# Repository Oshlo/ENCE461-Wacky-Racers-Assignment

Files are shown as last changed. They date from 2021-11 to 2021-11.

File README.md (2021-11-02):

Wacky Racers
===============

This contains a directory structure for your assignment.

doc -- documentation

hw  -- hardware

src -- source code

Assignment Instructions
-----------

The [instructions](https://eng-git.canterbury.ac.nz/wacky-racers/wacky-racers/-/raw/master/doc/instructions/instructions.pdf)
are in a PDF file stored in this repository (you'll also get a copy when you
fork the project)

Downloading
-----------

Your group leader should create a forked copy of the wacky-racers
git project and then add the other group members to the project.  This
can be done by:

1. Go to https://eng-git.canterbury.ac.nz/wacky-racers/wacky-racers

2. Click 'Fork' button.  This will create your own copy of the repository.

3. Click on the ‘Settings’ menu then click the 'Expand' button for
'Sharing and permissions'.  Change 'Project Visibility' to 'Private'.

4. Click on the 'Members' menu and add group members as Developers.

5. Using bash terminal (or other useful shell), enter the command:

```
$ git clone git@eng-git.canterbury.ac.nz:your-userid/wacky-racers.git
```

Note: this *requires* that you have setup SSH keys on your machine and added
them to your account. See
https://docs.gitlab.com/ee/ssh/#generating-a-new-ssh-key-pair for instructions
on generating an SSH key pair.

Or if you don't want to set up your SSH keys, you can clone using the HTTPS
protocol (we recommend the above method as it allows automatic authentication
without entering your password every single time you want to make changes):

```
$ git clone https://eng-git.canterbury.ac.nz/your-userid/wacky-racers.git
```

6. Add the original wacky-racers repository as upstream. This will allow you to
   pull updates/bug fixes we make during the assignment.
```
$ cd wacky-racers
$ git remote add upstream https://eng-git.canterbury.ac.nz/wacky-racers/wacky-racers.git
```

7. If we add more demo code or tweak the instructions, you can pull the updated
   stuff using
```
$ git pull upstream master
```

Visual Studio Code
------------------

VS Code is a modern and highly versatile text editor. With the right extensions,
it can be used to develop code for just about anything! This project has been
configured for VS Code on the ESL computers (but its relatively easy to modify
it to work on a home computer, be it Windows, Linux, or Mac). For the simplest
use, simply go `File -> Open Folder` and point it at the `wacky-racers`
repository. This will give you access to the build tools (CTRL-SHIFT-B) that
have been setup. These must be run from inside a program (i.e. ledflash1.c).
Finally, opening a program and pressing F5 will launch a debugging session that
will allow the use of breakpoints and variable inspection.

When building your programs, the BOARD configuration variable must be set. In VS
Code this is done by choosing your C++ configuration (bottom right of the
window) which by default will be either `hat` or `racer`.

As a side note, the compilation and debugging requires the installation of two
VS Code extensions:
* C/C++ (Microsoft)
* Native Debug (Web Freak)
  VS Code should automatically prompt you to install these when you open the
  wacky-racers directory.

Configuration
-------------

The src/boards directory contains a number of configurations; one for
the hat and racer boards.  Each configuration directory contains three
files:

* board.mk  --- this is a makefile fragment that specifies the MCU model, optimisation level, etc.
* target.h  --- this is a C header file that defines the PIO pins and clock speeds.
* config.h  --- this is a C header file that wraps target.h.  It's purpose is for porting to different compilers.

You will need to edit the target.h file for your board.

Compilation
-----------

Compilation requires a bare-metal ARM GCC toolchain arm-none-eabi.
See
http://ecewiki.elec.canterbury.ac.nz/mediawiki/index.php/ARM_toolchain
for installation details.

Compilation is performed using makefiles, since each application
requires many files.  Rather than having large makefiles, a heirarchy
of makefile fragments is employed.  Dependencies are automatically generated.

A board description can be selected with the BOARD environment
variable.  This can be defined for each command, for example,

```
$ BOARD=racer make program
```

Alternatively, this can be defined for a session

```
$ export BOARD=racer
$ make program
```

Before you can flash any code to the MCU, you need to disable the write-protection
bit in the non-volatile memory. This will need to be done once, and only needed again
if you erase your flash memory.
```
$ make bootflash
```

Each of the makefiles has the following phony targets:
* all  --- compile the application
* program --- compile the application and download to the MCU (you need Openocd running as a daemon)
* debug --- start the debugger GDB (you need Openocd running as a daemon)
* reset --- reset your MCU (you need Openocd running as a daemon)
* clean --- delete the executable and object files.   This is necessary when compiling for a different board.
* bootflash -- this needs to done once to set a bit in the SAM4S so that it will run your application and not its bootloader on reset.

Demo applications
-----------------

These are found in the test-apps directory.  These are board
independent and thus the specific board must be selected with the
BOARD environment variable.  Note, when debugging hardware it is much easier
to use a small test program rather than a large application.

There a number of variations of each test program.  As a rule, the larger the number, the fancier the level of abstraction.

I suggest trying the following programs:
* ledflash1 You will need to correctly define LED1_PIO in boards/xxxx/target.h  If this program does not run see  http://ecewiki.elec.canterbury.ac.nz/mediawiki/index.php/SAM4S_getting_started.
* pwm_test1 You will need to edit pwm_test1.c and define PWM1_PIO for an available PWM pin.  This program is useful for checking that the phase-locked loop (PLL) is correctly configured to generate the correct CPU clock frequency.  You should see a 100 kHz square wave using an oscilloscope connected to the specified PIO pin (provided it can be driven from the PWM peripheral).
* usb_vbus_test1 This will turn a LED on if the USB VBUS signal is detected when a USB cable is connected to a computer.  It is a simple example of using a PIO as an input.
* usbserial_hello1 This will repeatedly send "Hello world" to a computer via the USB CDC protocol.  If you have connected a USB cable to a computer running Linux, the Linux dmesg command should say someting about ttyACM0 detected.  If not see the troubleshooting section.   For more details, see http://ecewiki.elec.canterbury.ac.nz/mediawiki/index.php/USB_CDC.
* adc_test1 This reads from the AD5 and AD6 analogue inputs and prints the values to a computer with the USB CDC protocol.

Troubleshooting
---------------

If nothing runs, see  http://ecewiki.elec.canterbury.ac.nz/mediawiki/index.php/SAM4S_getting_started.

### USB

If USB does not work check boards/xxxx/target.h that the definition
of UDP_VBUS_PIO is correct for your board.  The default is

#define UDP_VBUS_PIO PA5_PIO

Note, the USB driver fires up when this PIO pin goes high in response to the
USB connector being plugged in to a computer.

If there is no VBUS detection, do not define this macro.

Watchdog timers
---------------

By default, the watchdog timers are disabled.  To enable them, use:

    #include "mcu.h"

    mcu_watchdog_enable ();

To reset the watchdog, in your main loop use:

    mcu_watchdog_reset ();

I/O
---

I/O is non-blocking so if data is not available, the functions return without waiting.   The underlying drivers use the POSIX I/O model.

Coding style
------------

For the curious, the GNU C coding style is used.  I worked as a
contractor for the USA company Cygnus Solutions (taken over by Redhat)
as a compiler engineer working on the GNU C compiler (GCC).  The
first-rule when working as a programmer for a company is to follow the
required coding style.  My text editor (emacs) is set up to default to
this style.

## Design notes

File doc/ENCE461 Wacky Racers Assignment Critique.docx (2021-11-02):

# ENCE461 Wacky Racers Assignment Critique

Adam Finlayson, 22219865, Group 17

# 1 Strengths

Design: Optional backup systems: We designed the board to have optional backups for both the piezo and IMU. It was important to have a backup for the IMU in case the soldering of the on board IMU did not work, and if the motor driver did not work for the piezo. (We did not end up needing to use either of these backups).

PCB Layout: Pin selection: when designing the components, the pins were chosen to work best with the expected layout of the board. Wiring: components that were switching the fastest were placed closest to the board and had the most direct connections (IMU, Radio, USB, Serial Debug), components that were switching slowly were placed further away and routed around more important components (Piezo, LEDs, Joystick, Buttons). The PCB layout required no changes or rewiring.

Overall wacky racer: Robust and had no problems uploading code.

# 2 Weaknesses

Design and PCB layout: the design and layout of the board had no weaknesses and did not interfere with our ability to complete this assignment.

Overall wacky racer: The control of the racer was difficult and needed more work. In testing the control was good enough, but in the final race the racer did not perform the same. This may have been a problem with the radio.

# 3 Improvements

I think we over designed the board, making it difficult to fit everything on the board. The external peripheral input and outputs were designed with no specific purpose in mind. The motor driver used to drive the piezo had a separate power circuit (own fuse and isolated), which was very unnecessary.

More testing on the radio would have allowed us to find better channels for clear transmission. I also wanted to implement a scanning function with the intent to search for anyone using channels (1 - 120), but still using the code 0x0123456789. I think this could have been interesting to test.

The control of the racer was more important than I expected, and we should have made a more robust control algorithm.

# 4 Contribution

I think I contributed well to this assignment. I did a lot of the work throughout the design and PCB layout stages, doing the device selection, pin selection and component layout and connection. I also actively contributed to the coding of the board, working with Harry to implement the functionality of our hat board. I also worked with Harry and Fraser to work out what information was important to send via the radios.

# 5 Recommendation to future students

The biggest recommendation I can make it to put a lot of time into the design and PCB layout of the board. This makes achieving the milestones throughout term 2 much easier to meet and generally reduces the stress of the project.

I also think that it is very important to utilize the help of the tutors. They are a great resource and can help fix problems quickly that would usually take far more time on your own.

This project is set up in an interesting way. I think it is important to lean into that fact and design the wacky racer to not only be functional but interesting. This makes the time required for this project much more bearable.

# 6 Recommendation to improve project

This project was both challenging and interesting which made it one of my favourite projects I have done. The only part of this project I did not like was my lack of understanding in how the background code worked. I tried to look through the code to figure out what was going on but had a hard time. I would have liked if there were a couple lectures or workshops to go over this so I could better understand what was going wrong when my code stopped working.

# 7 Peer assessment

My Board (Hat) | | Whole System
Name | Score | Name | Score
Harrison Pollard | 3 | Fraser Rose | 3
Adam Finlayson | 3 | Shan Zhong | 2
| | Harrison Pollard | 3
| | Adam Finlayson | 3

# 8 Workload

Hat | | | | Racer
Design | Build | Software | Testing | Design | Build | Software | Testing
60 | 5 | 40 | 20 | 0 | 0 | 0 | 10

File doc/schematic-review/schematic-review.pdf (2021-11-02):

# ENCE461 Schematic Review

### M.P. Hayes

Bring your schematics, printed on A3 paper

## 1 Common

1. Student names and group number in title block
2. Battery fusing (this is mandatory)
3. Use serial wire debug interface for programming
4. 3.3 V MCU regulator can be back driven
5. Short circuit protection for MCU pio pins going to external headers
6. Battery voltage monitoring
7. Do the analogue inputs to the MCU exceed 3.3 V?
8. LEDs for debugging
9. Jumpers for mode configuration (radio channel select)
10. Pullup resistors on TWI (I2C) bus
11. Test points
12. Ground test points
13. USB signals are not swapped
14. USB has series termination resistors (27 ohm)
15. VBUS detection through voltage divider to PIO pin. This is needed so that the MCU can tell when USB is plugged in or removed. You will also need diodes (or jumpers) so that the USB 5 V can be connected to the 5 V from the switching regulator.
16. Power supply filtering for radio (recommend ferrite bead or resistor in series with power rail with parallel capacitor)
17. The radio needs to be connected to SPI pins (MISO/PA12, MOSI/PA13, SCK/PA14)
18. Radio IRQ connected to MCU PIO pin
19. Radio uses SPI clock (SCK) not the TWI clock (TWCK)

1

20. TWI uses TWCK0/PA4 and TWD0/PA3 or TWCK1/PB5 and TWD1/PB4.
21. SAM4S erase pin on testpoint
22. SAM4S has 12 MHz crystal
23. Reset button connected to NRST pin
24. Power on/off button connected to WKUPn pin
25. Avoid PB4–PB5 for general I/O (they default to JTAG pins on reset but can be reconfigured in software)
26. Have external pull-down resistors to ensure chips are disabled on power-up
27. Have a few spare PIO pins connected to pads for last minute mods.

## 2 Hat board

1. Battery can be charged from USB
2. Fall-back option if IMU does not work
3. Nav-switch or joystick for remote control
4. Drive circuit for piezo tweeter
5. IMU nCS pin connected high to enable I2C operation
6. IMU AUX pins not connected

## 3 Racer board

1. MOSFET(s) for actuator (if use p-channel MOSFET need transistor to provide sufficient gate voltage to turn MOSFET off)
2. H-bridge driven by four PWM signals (it is best to use PWMHx, note PWMLx and PWMHx are complementary)
3. H-bridge AISEN and BISEN pins connected to ground (unless using current control)

2

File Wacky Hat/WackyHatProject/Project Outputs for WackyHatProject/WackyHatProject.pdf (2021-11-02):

Bill of Materials | Bill of Materials for Project [WackyHatProject.PrjPcb] (No PCB Document Selected)
Source Data From: | WackyHatProject.PrjPcb
Project: | | WackyHatProject.PrjPcb
Variant: | | None
Creation Date: 29/04/2021 | 8:33 am
Print Date: | 29-Apr-21 | 8:33:52 AM
Footprint | Comment | LibRef | Designator | Description | Quantity
CAPC1608L | 100nF | CC_100nF_0603 | C1, C3, C11, C22, C23, C24, C25, C27, C28, C29, C30, C31, C33
CAP CER 100nF X7R +-10% 50V 0603 | 13
CAPC1608L | 10nF | CC_10nF_0603 | C2, C4, C8, C9, C15, C18 | CAP CER 10nF X7R +-10% 50V 0603
6
CAPC1608L | 10uF | CC_10uF_0603 | C5, C7 | CAP CER 10UF X5R +-20% 6V3 0603
2
CAPC1608L | 2.2uF | CC_2.2uF_0603 | C6, C19 | CAP CER 2.2uF X5R +-20% 10V 0603
2
CAPC2012L | 10uF | CC_10uF_0805_10VC10, C26 | CAP CER 10uF X7R +-20% 10V 0805
2
CAPC3216L | 47uF | CC_47uF_1206 | C12 | CAP CER 47uF X5R -/+20% 6V 1206
1
NICH-1 | 100uF/16V | CA_100uF_16V | C13 | CAP ALUM 100uF 16V SMD
1
CAPC1608L | 1uF | CC_1uF_0603 | C14, C17 | CAP CER 1uF Y5V -20% +80% 16V 0603
2
CAPC1608N | 4.7uF | CC_4.7uF_0603 | C16, C32 | CAP CER 4.7uF X5R +-20% 10V 0603
2
CAPC1608L | 27pF | CC_27pF_0603 | C20, C21 | CAP CER 27pF NPO/COG +-5% 50V 0603
2
DO-214AA_SCLDIODE ZENER 5.6VSMBJ5339B-TP | D1, D3, D4, D5, D6, D7 | DIODE ZENER 5.6V 5W DO214AA
6
SMC | SCHOTTKY 30V 4AMBRS330T3G | D2 | DIODE SCHOTTKY 30V 4A SMC
1
WL-SMCW0603Blue | DL_150060BS75000DL1 | LED Blue 270mcd 0603 SMD
1
WL-SMCW0603Dark Green | DL_150060GS75000DL2 | LED Dk Green 430mcd 0603 SMD
1
RESC3216N | 5A | FS_Fuse_5.0A | F1 | Fuse 5.0A Fast Acting 1206 SMD
1
RESC3216N | 2A | FS_Fuse_2.0A | F2 | Fuse 2.0A Very Fast Acting 1206 SMD
1
MOLEX_KK_10_HDR 10 Pin Molex KK | Hdr JA_MOLEX_KK_10POS H1 | CONN HEADER 10POS 2.54mm VERT_ Thru Hole
1
MOLEX_KK_2_HDR 2 Pin Molex KK HDRJA_MOLEX_KK_2POS H2, H3 | CONN HEADER 2POS 2.54mm VERT_Thru | Hole
2
MOLEX_KK_3_HDR 3 Pin Molex KK HdrJA_MOLEX_KK_3POS H4 | CONN HEADER 3POS 2.54mm VERT_Thru | Hole
1
BATT_HEADER_3POS Battery_HEADER_3pin Battery_HEADER_3pin H5 | 3Pin Header 2.54mm spacing
1
FCI_USB_10118194-0001LF JS_USB_MICRO_BJS_USB_MICRO_B_SMT H6 | CONN USB MICRO B RECPT SMT R/A
1
MOLEX_KK_4_HDR 4 Pin Molex KK HdrJA_MOLEX_KK_4POS H7, H8 | CONN HEADER 4POS 2.54mm VERT_Thru | Hole
2
IDC2.54-V10D | Header 5X2 Vert | JA_HDR_IDC_5X2_VERT H9 | IDC Header, 2,54mm, 10-Pin, Vert
1
JMP2.54-CO | 100Mil Jumper | TP_JUMPER_COJ1 | 2.54mm Jumper change over, Thru Hole
1
INDC3216L | 1A max, Idc 0.3R, IN_Ferrite-Bead | L1, L3 | Ferrite Bead, Rdc 0.3R, Z100MHZ 600R, Imax 1A, SMD 1206 2
INDUCTOR5u2IND 5.2UH 6A | CDRH104RNP-5R2NC L2 | FIXED IND 5.2UH 6A 22 MOHM SMD
1
SOT23_L | SSM3J328R,LF | TM_SSM3J328R | Q1, Q2 | MOSFET P-CH 20V 6A SOT23-3
2
RESC1608L | 0R | RS_0R0 | R1, R2, R3, R5, R6, R13, R16, R17 | RES 0.0 OHM 1/10W 5% 0603 SMD
8
RESC1608L | 1K | RS_1K | R4 | RES 1.0K OHM 1/10W 5% 0603 SMD
1
RESC1608L | 270R | RS_270R | R7, R8 | RES 270 OHM 1/10W 5% 0603 SMD
2
RESC1608L | 15K | RS_15K | R9 | RES 15.0K OHM 1/10W 5% 0603 SMD
1
RESC1608N | 47K | RS_47K | R10 | RES 47.0K OHM 1/10W 5% 0603 SMD
1
RESC1608L | 27K | RS_27K | R11 | RES 27K OHM 1/10W 5% 0603 SMD
1
RESC1608L | 36K | RS_36K | R12 | RES 36K OHM 1/10W 5% 0603 SMD
1
RESC1608L | 47K | RS_47K | R14 | RES 47.0K OHM 1/10W 5% 0603 SMD
1
RESC1608L | 24K | RS_24K | R15 | RES 24K OHM 1/10W 5% 0603 SMD
1
RESC1608L | 10K | RS_10K | R18, R19 | RES 10.0K OHM 1/10W 5% 0603 SMD
2
RESC1608L | 27R | RS_27R | R20, R21 | RES 27 OHM 1/10W 5% 0603 SMD
2
RESC1608L | 2K | RS_2K | R22, R23 | RES 2K OHM 1/10W 5% 0603 SMD
2
RESC3216L | 1R | RT_1R | R24 | RES 1R OHM 1/4W 5% 1206 SMD
1
RESC1608L | 360R | RS_360R | R25, R26 | RES 360 OHM 1/10W 5% 0603 SMD
2
DIP_SW_4WAY_SMD - W_SW DIP-4 | WS_SW DIP-4 | S1 | DIP Switch, 4 Position, SPST SMD
1
EVQPNF05M | RESET | WS_EVQPNF05MS2 | Panasonic 6 x 3.5mm SMD Light Touch Switch Type SMD1
EVQPNF05M | SLEEP | WS_EVQPNF05MS3 | Panasonic 6 x 3.5mm SMD Light Touch Switch Type SMD1
SOT23_L | BSH105,215 | TM_BSH105 | T1 | MOSFET N-CH 20V 1.05A SOT-23
1
TP_0603 | IMU Int Alt | TP_0603 | TP1 | Test Point 1.65X0.9X1.2mm SMD
1
TP_0603 | IMU Data Alt | TP_0603 | TP2 | Test Point 1.65X0.9X1.2mm SMD
1
TP_0603 | IMU Clock Alt | TP_0603 | TP3 | Test Point 1.65X0.9X1.2mm SMD
1
TP_0603 | Piezo Alt | TP_0603 | TP4 | Test Point 1.65X0.9X1.2mm SMD
1
TP_0603 | Peizo Alt | TP_0603 | TP5 | Test Point 1.65X0.9X1.2mm SMD
1
TP_0603 | TP_0603 | TP_0603 | TP6 | Test Point 1.65X0.9X1.2mm SMD
1
TP_0603 | ERASE | TP_0603 | TP7 | Test Point 1.65X0.9X1.2mm SMD
1
TP_0603 | Piezo 22 | TP_0603 | TP12 | Test Point 1.65X0.9X1.2mm SMD
1
TP_0603 | Piezo 21 | TP_0603 | TP13 | Test Point 1.65X0.9X1.2mm SMD
1
TP_0603 | Piezo 12 | TP_0603 | TP14 | Test Point 1.65X0.9X1.2mm SMD
1
TP_0603 | Piezo 11 | TP_0603 | TP15 | Test Point 1.65X0.9X1.2mm SMD
1
TP_0603 | 3V3 Radio | TP_0603 | TP16 | Test Point 1.65X0.9X1.2mm SMD
1
TP_0603 | VPIEZO | TP_0603 | TP17 | Test Point 1.65X0.9X1.2mm SMD
1
TP_0603 | 5V | TP_0603 | TP18 | Test Point 1.65X0.9X1.2mm SMD
1
TP_0603 | VBUS | TP_0603 | TP19 | Test Point 1.65X0.9X1.2mm SMD
1
TP_0603 | 3V3 | TP_0603 | TP20 | Test Point 1.65X0.9X1.2mm SMD
1
TP_0603 | VBATT | TP_0603 | TP21 | Test Point 1.65X0.9X1.2mm SMD
1
TP_0603 | Buzzer Low | TP_0603 | TP22 | Test Point 1.65X0.9X1.2mm SMD
1
TP_0603 | SWDIO | TP_0603 | TP23 | Test Point 1.65X0.9X1.2mm SMD
1
TP_0603 | LED Signal | TP_0603 | TP24 | Test Point 1.65X0.9X1.2mm SMD
1
TP_0603 | Radio MISO | TP_0603 | TP25 | Test Point 1.65X0.9X1.2mm SMD
1
TP_0603 | Radio MOSI | TP_0603 | TP26 | Test Point 1.65X0.9X1.2mm SMD
1
TP_0603 | IMU DATA | TP_0603 | TP27 | Test Point 1.65X0.9X1.2mm SMD
1
TP_0603 | IMU INT | TP_0603 | TP28 | Test Point 1.65X0.9X1.2mm SMD
1
TP_0603 | Buzzer High | TP_0603 | TP29 | Test Point 1.65X0.9X1.2mm SMD
1
TP_0603 | SWCLK | TP_0603 | TP30 | Test Point 1.65X0.9X1.2mm SMD
1
TP_0603 | Radio CLK | TP_0603 | TP31 | Test Point 1.65X0.9X1.2mm SMD
1
TP_0603 | IMU CLK | TP_0603 | TP32 | Test Point 1.65X0.9X1.2mm SMD
1
Quad24 | Comment | MPU-9250 | U1 | 9 axis IMU
1
NRF24 | nRF24 SMD | NRF24 | U2 | nRF24 SMD Module
1
HTSOP16 | DRV8833 | DRV8833 | U3 | Dual H-Bridge Motor Driver 1.5A
1
SOT23-6_N | SN74LVC1T45 | SN74LVC1T45 | U4, U7, U8 | 1.8V - 5V level converter
3
RD_8_1 | Comment | ADP2302ARDZ-5.0-R7 U5 | IC REG BUCK 5V 2A 8SOIC
1
SOT95P280X145-5N CAT6219-330TDGT3SV_CAT6219-330TDGT3 U6, U9 | IC REG LIN 3.3V 500MA TSOT23-5
2
LQFP64_L | Comment | SE_ATSAM4S16BA-MU U10 | IC MCU 32BIT 512KB FLASH 64LQFP
1
Joystick_Sw | Joystick 10k with | SwJoystick 10k with | SwVR1 | JOYSTICK 10K OHM 2 AXIS TH
1
6.0X3.5-4 | 12MHz | XT_CRYSTAL_12MHz_18pF Y1 | CRYSTAL 12MHZ 18PF 6X3.5mm SMD
1
Approved Notes | 129
Altium Limited Confidential | 29/04/2021 | Page 1

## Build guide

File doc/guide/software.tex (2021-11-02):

\chapter{Software}

\section{Preparation}
\label{preparation}

Do not underestimate the effort required to flash your first LED. You
require:

\begin{itemize}
\item
  A computer with \program{git} installed and a useful shell program such as
  \program{bash}. UC has a \href{http://ucmirror.canterbury.ac.nz/}{mirror}
  for a variety of Linux distributions; we recommend Ubuntu or Mint.
\item
  A working ARM toolchain (arm-none-eabi-gcc/g++ version 4.9.3 or newer).
\item
  \program{OpenOCD} V0.8.0 or later.
\item
  An ST-link programmer and 10-wire ribbon cable for programming. You
  can get the adaptor from Scott Lloyd in the SMT lab. You will need
  to make your own cable (For a grey ribbon cable, align the red
  stripe with the small arrow denoting pin 1 on the connector. For a
  rainbow ribbon cable, connect the brown wire to pin 1.). There are
  two variants of the ST-link programmer with \textbf{different
    pinouts} so you may need to customise your programming cable.
\item
  Plenty of gumption.
\end{itemize}

\subsection{Toolchain}
\label{toolchain}

The required software is installed on computers in the ESL and
CAE. It should run under both Linux and Windows. If there is a
problem ask the technical staff.

If you are working from a personal Linux computer make sure to update
your machine to the latest software versions. This is particularly
important for the ARM toolchain (arm-none-eabi-gcc/g++) which should be
at version 4.9.3 or newer. You can do this with the following command
for an Ubuntu or Mint distribution:

\begin{minted}{bash}
$ sudo apt update && sudo apt upgrade}
\end{minted}

For MacOS machines that have \href{https://brew.sh}{homebrew} installed,
you can use the following command:

\begin{minted}{bash}
$ brew install openocd git}
$ brew cask install gcc-arm-embedded}
\end{minted}

\subsection{Project forking}
\label{project-forking}

The example software is hosted on the eng-git \program{Git} server at
\href{https://eng-git.canterbury.ac.nz/wacky-racers/wacky-racers-2021}{\url{https://eng-git.canterbury.ac.nz/wacky-racers/wacky-racers-2021}}.
Your group leader should have forked this template project. This creates
your own group copy of the project on the eng-git server that you can
modify, add members, etc. To fork the project:

\begin{enumerate}
\item
  Go to
  \href{https://eng-git.canterbury.ac.nz/wacky-racers/wacky-racers-2021}{\url{https://eng-git.canterbury.ac.nz/wacky-racers/wacky-racers-2021}}.
\item
  Click the `Fork' button. This will create a copy of the main repository
  for the project.
\item
  Click on the `Settings' menu then click the `Expand' button for
  `Sharing and permissions'. Change `Project Visibility' to `Private'.
\item
  Click on the `Members' menu and add group members as Developers.
\end{enumerate}

\subsection{Project cloning}
\label{project-cloning}

Once your project has been forked from the template project, each group
member needs to clone it. This makes a local copy of your project on
your computer. 

If you are using an ECE computer, it is advised that you clone the
project on to a removable USB flash drive. This will make git operations
and compilation a 100 times faster than using the networked file system.

There are two ways to clone the project. If you are impatient and do not
mind having to enter a username and password for every git pull and push
operation use:
%
\begin{minted}[breaklines]{bash}
$ git clone https://eng-git.canterbury.ac.nz/groupleader-userid/wacky-racers-2021.git wacky-racers
\end{minted}

Otherwise, set up \program{ssh-keys} and use:
%
\begin{minted}[breaklines]{bash}
$ git clone git@eng-git.canterbury.ac.nz:groupleader-userid/wacky-racers-2021.git wacky-racers
\end{minted}

You can several different cloned copies of your project in different
directories. Sometimes if you feel that the world, and \program{git} in
particular, is against you, clone a new copy, using:

\begin{minted}[breaklines]{bash}
$ git clone https://eng-git.canterbury.ac.nz/groupleader-userid/wacky-racers-2021.git wacky-racers-new
\end{minted}

\subsection{Configuration}
\label{configuration}

Each board has different PIO definitions and requires its own
configuration information. The \wfile{boards}
directory contains a number of configurations; one for the hat and racer
boards. Each configuration directory contains three files:

\begin{itemize}
\item
  \file{board.mk} is a makefile fragment that specifies the MCU model,
  optimisation level, etc.
\item
  \file{target.h} is a C header file that defines the PIO pins and
  clock speeds.
\item
  \file{config.h} is a C header file that wraps target.h. It's purpose
  is for porting to different compilers.
\end{itemize}

\textbf{You will need to edit the target.h file for your board} and set
the definitions appropriate for your hardware. Here's an excerpt from
\file{target.h} for a hat board:

\begin{minted}{C}
/* USB  */
#define USB_VBUS_PIO PA5_PIO

/* ADC  */
#define ADC_BATTERY PB3_PIO
#define ADC_JOYSTICK_X PB2_PIO
#define ADC_JOYSTICK_Y PB1_PIO

/* IMU  */
#define IMU_INT_PIO PA0_PIO

/* LEDs  */
#define LED1_PIO PA20_PIO
#define LED2_PIO PA23_PIO
\end{minted}

\section{First program}
\label{first-program}

Your first program to test your board should only flash an LED (the
hello world equivalent for embedded systems). The key to testing new
hardware is to have many programs that only do one simple task each.

\subsection{OpenOCD}
\label{openocd}

\program{OpenOCD} is used to program the SAM4S. For this assignment,
we are using a ST-link programmer to connect to the SAM4S using serial
wire debug (SWD). This connects to your board with a 10-wire ribbon
cable and an IDC connector.

\begin{enumerate}
\item
  Before you start, disconnect the battery and other cables from your
  PCB.
\item
  Connect a 10-wire ribbon cable from the ST-link programmer to the
  programming header on your PCB. This will provide 3.3 V to your
  board so your green power LED should light.
\item
  Open a \textbf{new terminal window} and start \program{OpenOCD}.
\end{enumerate}

\begin{minted}{bash}
$ cd wacky-racers
$ openocd -f src/mat91lib/sam4s/scripts/sam4s_stlink.cfg
\end{minted}

All going well, the last line output from \program{OpenOCD} should be:

\begin{verbatim}
Info : sam4.cpu: hardware has 6 breakpoints, 4 watchpoints
\end{verbatim}

Congrats if you get this! It means you have correctly soldered your
SAM4S. If not, do not despair and do not remove your SAM4S. Instead,
see \protect\hyperref[troubleshooting]{troubleshooting}.

\subsection{LED flash program}
\label{led-flash-program}

For your first program, use
\wfile{test-apps/ledflash1/ledflash1.c}. The macros
\code{LED1_PIO} and \code{LED2_PIO} need to be defined in
\file{target.h} (see
\protect\hyperref[configuration]{configuration}). If your LEDs are
active high, replace 1 with 0 in the LED config structures.

\inputminted{C}{../../src/test-apps/ledflash1/ledflash1.c}

\subsection{Compilation}
\label{compilation}

Due to the many files required, compilation is performed using
makefiles.

The demo test programs are generic and you need to specify which board
you are compiling them for. The board configuration file can be chosen
dynamically by defining the environment variable \code{BOARD}. For
example:
%
\begin{minted}{bash}
$ cd src/test-apps/ledflash1
$ BOARD=racer make
\end{minted}

If all goes well, you should see at the end:
%
\begin{verbatim}
   text    data     bss     dec     hex filename
  19432    2420    2732   24584    6008 ledflash1.bin
\end{verbatim}

To avoid having to specify the environment variable \code{BOARD}, you
can define it for the rest of your session using:
%
\begin{minted}{bash}
$ export BOARD=racer
\end{minted}
%
and then just use:
%
\begin{minted}{bash}
$ make
\end{minted}

Note, if you compile with the \code{BOARD} environment variable set incorrectly, use:
%
\begin{minted}{bash}
$ make clean
$ make  
\end{minted}
%
to delete all the object files and rebuild.

\subsection{Booting from flash memory}
\label{booting-from-flash-memory}

By default the SAM4S runs a bootloader program stored in ROM. The SAM4S
needs to be configured to run your application in flash memory.

If \program{OpenOCD} is running you can do this with:

\begin{minted}{bash}
$ make bootflash
\end{minted}

Unless you force a complete erasure of the SAM4S flash memory by
connecting the \pin{ERASE} pin to 3.3 V, you will not need to repeat
this command.

\subsection{Programming}
\label{programming}

If \program{OpenOCD} is running you can store your program in the flash
memory of the SAM4S using:

\begin{minted}{bash}
$ make program
\end{minted}

When this finishes, one of your LEDs should flash. If so, congrats! If
not, see \protect\hyperref[troubleshooting]{troubleshooting}.

To reset your SAM4S, you can use:
%
\begin{minted}{bash}
$ make reset
\end{minted}

\section{USB interfacing}
\label{usb-interfacing}

To help debug your programs, it is wise to use \wikiref{USB CDC}{USB
  CDC}.  This is a serial protocol for USB.  With some magic, the
stdin, stdout, and stderr streams can sent over USB.  For example,
here's an example program
\wfile{test-apps/usb_serial_test1/usb_serial_test1.c}.

\inputminted{C}{../../src/test-apps/usb_serial_test1/usb_serial_test1.c}

Note, the string \code{"/dev/usb_tty"} is used to name the USB serial
device on the SAM4S so that it can be used by the C stdio function
\code{freopen}\footnote{When running a program with an operating
  system, this is all set up before \code{main} is called.}.

To get this programme to work you need to compile it and program the SAM4S using:

\begin{minted}{bash}
$ cd wacky-racers/src/test-apps/usb_serial_test1
$ make program
\end{minted}

You then need to connect your computer to the USB connector on your PCB.
If you are running Linux, run:
%
\begin{minted}{bash}
$ dmesg
\end{minted}

This should say something like:
%
\begin{verbatim}
Apr 30 11:03:50 thing4 kernel: [52704.481352] usb 2-3.3: New USB device found, idVendor=03eb, idProduct=6202
Apr 30 11:03:50 thing4 kernel: [52704.481357] usb 2-3.3: New USB device strings: Mfr=1, Product=2, SerialNumber=3
Apr 30 11:03:50 thing4 kernel: [52704.482060] cdc_acm 2-3.3:1.0: ttyACM0: USB ACM device
\end{verbatim}

Congrats if you see \texttt{ttyACM0:\ USB\ ACM\ device}!  If not, see
\wikiref{USB_debugging}{USB debugging}.

You can now run a \wikiref{Serial_terminal_applications}{serial
  terminal program}. For example, on Linux:

\begin{minted}{bash}
$ gtkterm -p /dev/ttyACM0
\end{minted}

All going well, this will repeatedly print 'Hello world'.

If you get an error 'device is busy', it is likely that the ModemManager
program has automatically connected to your device on the sly. This
program should be disabled on the ECE computers. For more about this and
using other operating systems, see \wikiref{USB CDC}{USB CDC}.

\section{Test programs}
\label{test-programs}

There are a number of test programs in the directory
\wfile{test-apps}. Where possible these are written to be
independent of the target board using configuration files (see
\protect\hyperref[configuration]{configuration}).

\subsection{PWM test}
\label{pwm-test}

The program \wfile{test-apps/pwm_test2/pwm_test2.c} provides an
example of driving PWM signals.

\inputminted{C}{../../src/test-apps/pwm_test2/pwm_test2.c}

Notes:
%
\begin{enumerate}
\item
  This is for a different H-bridge module that requires two PWM signals
  and forward/reverse signals. You will need to generate four PWM
  signals or be clever with two PWM signals.
\item
  The \code{pwm_cfg_t} structure configures the frequency, duty
  cycle and alignment of the output PWM.
\item The frequency is likely to be too high for your motor.
\item \code{pwm_channels_start} is used to start the PWM channels simultaneously.  
\end{enumerate}

The most likely problem is that you have not used a PIO pin that can
be driven as a PWM output. The SAM4S can generate four independent
hardware PWM signals. See \wfile{mat91lib/pwm/pwm.c} for a list of
supported PIO pins. Note, \pin{PA16}, \pin{PA30}, and \pin{PB13} are
different options for PWM2.

To drive the motors you will need to use a bench power supply. Start
with the current limit set at 100\,mA maximum in case there are any
board shorts.  When all is well, you can increase the current limit.

\subsection{IMU test}
\label{imu-test}

The MPU9250 IMU connects to the SAM4S using the I2C bus (aka TWI bus).
The program \wfile{test-apps/imu_test1/imu_test1.c} provides an
example of using the MPU9250 IMU.  All going well, this prints three
16-bit acceleration values per line to USB CDC. Tip your board over,
and the the third (z-axis) value should go negative since this
measures the effect of gravity on a little mass inside the IMU pulling
on a spring.

If you get `ERROR: can't find MPU9250!', the main reasons are:

\begin{enumerate}
\item
  You have specified the incorrect address. Use \code{MPU_0} if the
  AD0 pin is connected to ground otherwise use \code{MPU_1}.
\item
  You are using TWI1. The \pin{PB4} and \pin{PB5} pins used by TWI1 default to JTAG
  pins. See \protect\hyperref[disabling-jtag-pins]{disabling JTAG pins}.
\item
  You do not have TWI/I2C pull-up resistors connected to 3V3 or the
  wrong resistor values. Use a scope to look at the signals \pin{TWCK/SCL}
  and \pin{TWD/SDA}.
\item
  Check that the auxiliary I2C bus signals are not connected
  (otherwise the magnetometer will not respond).  
\item
  You have a soldering problem. Try pressing on a side of the IMU with a
  fingernail to see if it starts working; you might have a dry joint.
\end{enumerate}

Other problems:
%
\begin{enumerate}
\item If you reset the SAM4S in the middle of a transaction with the
IMU, the IMU gets confused and holds the \pin{TWD/SDA} line low. This
requires recycling of the power or sending out some dummy clocks on
the \pin{TWCK/SCL} signal.
\end{enumerate}

\subsection{Radio test}
\label{radio-test}

The program \wfile{test-apps/radio_tx_test1/radio_tx_test1.c} provides
an example of using the radio as a transmitter.

The companion program
\wfile{test-apps/radio_rx_test1/radio_rx_test1.c} provides an example
of using the radio as a receiver.

Notes:
%
\begin{enumerate}
\item
  Both programs must use the same RF channel and the same address. Some
  RF channels are better than others since some overlap with WiFi
  and Bluetooth. The address is used to distinguish devices
  operating on the same channel. Note, the transmitter expects an
  acknowledge from a receiver on the same address and channel.
\item
  The radio `write` method blocks waiting for an auto-acknowledgement
  from the receiver device. This acknowledgement is performed in
  hardware. If no acknowledgement is received, it retries for up to 15
  times. The auto-acknowledgement and number of retries can be
  configured in software.
\end{enumerate}

If you cannot communicate between your hat and racer boards, try
communicating with the radio test modules Scott Lloyd has in the SMT
lab.

\section{Your hat/racer program}
\label{your-hatracer-program}

We recommend that build your programs incrementally and that you poll
your devices with a paced loop and not use interrupts.  It is a good
idea to disable the \hyperref[watchdog-timer]{watchdog timer} until
you have robust code.

\section{Howtos}
\label{howtos}

\subsection{Delaying}

mat91lib provides a macro \code{DELAY_US} in
\wfile{mat91lib/delay.h} for a busy-wait delay in microseconds
(this can be a floating point value).  The CPU just spins for a
precomputed number of clock cycles.  The argument should be a constant
so the compiler can compute the number of clock cycles.  This function
needs to be compiled with optimisation.

mat91lib also provides a function \code{delay_ms} for a busy-wait
delay in milliseconds (this must be an integer).  All this function
does is call \code{DELAY_US (1000)} the required number of times.

An example program is \wfile{test-apps/delay_test1/delay_test1.c}.

\subsection{Reading from ADC}
\label{ADC}

\wfile{test-apps/adc_usb_serial_test1/adc_usb_serial_test1.c} shows
how to read a single ADC channel.  \textbf{Note, this is not tested!}
For more details see \wfile{mat91lib/adc/adc.h}.

\wfile{test-apps/adc_usb_serial_test2/adc_usb_serial_test2.c} shows
how to read from two multiplexed ADC channels.  \textbf{Note, this is
  not tested!}

The ADC can be also set up to stream data continuously; this is a lot
more complicated.

\subsection{Reading from pushbutton}
\label{pushbutton}

\wfile{test-apps/button_test2/button_test2.c} shows the use of a
simple button driver to read a pushbutton.  This driver does button
debouncing and state-transition detection.  For more details see
\wfile{mmculib/button/button.h}.

\subsection{Disabling JTAG pins}
\label{disabling-jtag-pins}

By default \pin{PB4} and \pin{PB5} are configured as JTAG pins. You can turn
them into PIO pins or use them for TWI1 using:
%
\begin{minted}{C}
#include "mcu.h"

void main (void)
{
    mcu_jtag_disable ();
}
\end{minted}

\subsection{Watchdog timer}
\label{watchdog-timer}

The watchdog timer is useful for resetting the SAM4S if it hangs in a
loop.  It is disabled by default but can be enabled using:
%
\begin{minted}{C}
#include "mcu.h"

void main (void)
{
    mcu_watchdog_enable ();
   
    while (1)
    {
         /* Do your stuff here.  */

         mcu_watchdog_reset ();
    }
}
\end{minted}

\section{Under the bonnet}
\label{under-the-bonnet}

\file{mmculib} is a library of C drivers, mostly for performing high-level I/O.
It is written to be microcontroller neutral.

\file{mat91lib} is a library of C drivers specifically for interfacing
with the peripherals of Atmel AT91 microcontrollers such as the Atmel
SAM4S. It provides the hardware abstraction layer.

The building is controlled by \wfile{mat91lib/mat91lib.mk}. This is a
makefile fragment loaded by \wfile{mmculib/mmculib.mk}.
\file{wacky-reacers/src/mat91lib/mat91lib.mk} loads other makefile fragments for each
peripheral or driver required. It also automatically generates
dependency files for the gazillions of other files that are required to
make things work.

\section{Git}
\label{git}

To properly use git you should commit and push often. The smaller the
changes and the more often you make per commit, the smaller the chance
of the dreaded merge conflict.

\subsection{Git pulling from upstream}
\label{git-pulling-from-upstream}

To be able to get updates if the template project is modified you will
need to:

\begin{minted}{bash}
$ cd wacky-racers 
$ git remote add upstream https://eng-git.canterbury.ac.nz/wacky-racers/wacky-racers-2021.git  
\end{minted}

Again if you do not want to manually enter your password (and have
ssh-keys uploaded) you can use:
%
\begin{minted}[breaklines]{bash}
$ cd wacky-racers 
$ git remote add upstream git@eng-git.canterbury.ac.nz:wacky-racers/wacky-racers-2021.git
\end{minted}

Once you have defined the upstream source, to get the updates from the
main repository use:
%
\begin{minted}{bash}
$ git pull upstream master
\end{minted}

If you enter the wrong URL make a mistake, you can list the remote
servers and delete the dodgy entry using:

\begin{minted}{bash}
$ git remote -v
$ git remote rm upstream
\end{minted}

Note, \textbf{origin} refers to your group project and \textbf{upstream}
refers to the template project that origin was forked from.

\subsection{Git merging}
\label{git-merging}

The bane of all version control programs is dealing with a merge
conflict. You can reduce the chance of this happening by committing and
pushing faster than other people in your group.

If you get a message such as:

\begin{verbatim}
From https://eng-git.canterbury.ac.nz/wacky-racers/wacky-racers-2021
 * branch            master     -> FETCH_HEAD
error: Your local changes to the following files would be overwritten by merge:
    src/test-apps/imu_test1/imu_test1.c
Please, commit your changes or stash them before you can merge.
\end{verbatim}

what you should so is:

\begin{minted}{bash}
$ git stash
$ git pull
$ git stash pop
# You may now have a merge error.  You will now have to edit the offending file, in this case imu_test1.c
# Once the file has been fixed
$ git add src/test-apps/imu_test1/imu_test1.c
$ git commit -m "Fix merge"
\end{minted}

Sometimes when you do a git pull you will be thrown into a text editor
to type a merge comment. The choice of editor is controlled by an
environment variable \code{EDITOR}. On the ECE computers this defaults
to emacs. You can changed this by adding a line such as the following to
the \file{.bash\_profile} file in your home directory.

\begin{minted}{bash}
$ export EDITOR=geany
\end{minted}

By the way, to exit emacs type ctrl-x ctrl-c, to exit vi or vim type \code{:q!}

\textbf{Please do not edit the files in the mat91lib, mmculib, and
wackylib} directories since this can lead to merge problems in the
future. If you find a bug or would like additional functionality let MPH
or one of the TAs know.

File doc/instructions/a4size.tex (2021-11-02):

% A4 210 mm x 298 mm
\pagestyle{plain}			% the default anyway
\pagenumbering{arabic}
\setlength{\oddsidemargin}{0mm}
\setlength{\evensidemargin}{-14mm}
\setlength{\marginparwidth}{0cm}
\setlength{\marginparsep}{0cm}
\setlength{\topmargin}{2mm}
\setlength{\headheight}{0mm}
\setlength{\headsep}{0cm}
\setlength{\textheight}{240mm}
\setlength{\textwidth}{168mm}
\setlength{\topskip}{0mm}
\setlength{\footskip}{10mm}
%
\setlength{\parindent}{8ex}

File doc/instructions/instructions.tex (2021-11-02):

\documentclass[11pt, a4paper]{article}
\title{Wacky Racers 2021 Instructions}
\author{Michael Hayes, Ben Mitchell}
\date{Version 4.2, \today}

\usepackage[margin=1in]{geometry}
\usepackage{parskip}
\usepackage{float}
\usepackage{todonotes}
\presetkeys{todonotes}{inline}{}
\usepackage{graphicx}
\usepackage[T1]{fontenc}
\usepackage{makecell}
\usepackage[breaklinks=true]{hyperref}
\usepackage{tabularx}
\usepackage{subcaption}
\usepackage{listings}
\usepackage{siunitx}
\usepackage{circuitikz}
\usepackage{tikz}
\usetikzlibrary{arrows}

\newcommand{\code}[1]{\texttt{#1}}

\begin{document}
\maketitle

\section{Introduction}

The purpose of this assignment is to design, build, and program an
embedded system using an ARM microcontroller and surface mount
technology.

The goal for each group of four students is to build a remote
controlled vehicle (the Wacky Racer) and its controller (the Wacky
Hat).  At the conclusion of the assignment there will be a dastardly race!

Each group is comprised of two sub-groups of two students.  One of
these subgroups constructs the Wacky Racer and the other constructs
the Wacky Hat.  You may be asking why is the Wacky Hat called the
Wacky Hat?  Well, a hat that controls a remote vehicle using head
motions is not an ordinary hat!

\section{Requirements}

The following requirements are mandatory if you wish to maximise your
marks.

\subsection{Wacky racer}

\begin{enumerate}
\item The chassis is to be constructed by each group.  These can be 3-D printed,
  constructed from Perspex or wood, etc.  A standard chassis is available from
  the Electronics Lab technician (Diego Ramirez).  The electronics must be
  visible on top of the chassis.
\item Have a standard working bump sensor (supplied).
\item Locomotion can only use two 6\,V DC motors (supplied).
\item Everything must be powered from a single 5-cell NiMH battery pack (supplied).
\item Use a single four layer printed circuit board of dimension 85\,mm$\times$64\,mm.
\item Use an ARM microcontroller (Atmel SAM4S8).
\item Drive the motors using H-bridges (Texas Instruments DRV8833 dual
  H-bridge is recommended).
\item Regulate the nominal battery voltage to 5\,V with a buck
  regulator IC (ADP2302ARDZ-50).
\item Be decorated with an LED tape (supplied) controlled by the MCU.
\item Use a USB interface for debugging.
\item Use a serial wire debug interface for MCU programming/debugging.
\item Have adequate battery fusing and reverse polarity protection.
\item Have a sleep button.
\item If the battery voltage drops below 5\,V, an LED should flash and high power draw devices should be disabled.
\item Interface to the Wacky Hat with a Nordic nRF24 SMD radio module.
\item Have four jumper selectable radio channels.
\item Have a mounted RFID card (supplied) that can be read by the Wacky ramps.
\item Be humorous.
\end{enumerate}

Each Wacky Racer can have a dastardly means of hindering another
team's Wacky Racer.  However, you cannot:
%
\begin{itemize}
\item Damage or destroy another Wacky racer
\item Damage the venue
\item Injure a spectator
\item Jam the radio signals
\end{itemize}

\vspace{1cm}

\begin{figure}[h]
    \centering
    \input{racer_top_level.tex}
    \caption{Racer board top level diagram.}
\end{figure}

\vfill\pagebreak

\subsection{Wacky hat}

\begin{enumerate}
\item Construct a Wacky Hat that contains all the electronics.
\item Everything must be powered from a single 5-cell NiMH battery pack (supplied).
\item Have adequate battery fusing and reverse polarity protection.
\item Use a single four layer printed circuit board of dimension 85\,mm$\times$64\,mm.
\item Use an ARM microcontroller (Atmel SAM4S8).
\item Regulate the nominal 6\,V battery voltage to 5\,V with a buck
  regulator IC (ADP2302ARDZ-50).
\item Be decorated with an LED tape (supplied) controlled by the MCU.
\item Use an I2C IMU (MPU-9250) for head motion detection.
\item Use a USB interface for debugging.
\item Use a serial wire debug interface for MCU programming/debugging.
\item Have a joystick in case the IMU does not work.
\item Have a sleep button.
\item If the battery voltage drops below 5\,V, an LED should flash and high power draw devices should be disabled.
\item Play sound when the bumper is hit.
\item Interface to the Wacky Racer with a Nordic nRF24 SMD radio module.
\item Have four jumper selectable radio channels.
\item Be humorous.
\end{enumerate}

%\vspace{1cm}

\begin{figure}[h]
  \centering
  \input{hat_top_level.tex}
  \caption{Racer hat top level diagram.}
\end{figure}

\pagebreak

\section{Assignment schedule}

The planned activities for the timetabled labs in the Embedded Systems
Lab (ESL) are:
%
\begin{flushleft}
  \begin{tabular}{ c l l }
    Week            &  Assistance  &  Assessment \\
    \hline \hline
    T1-1 & Altium tutorial 1 (schematics)  & \\
    T1-2 & Altium help      & Schematic submission for review (Friday 5pm) \\
    T1-3 & Schematic review & \\
    T1-4 & Altium tutorial 2 (PCB) &          \\
    T1-5 & Altium help      & PCB submission 1    \\
    T1-6 & Altium help      & PCB submission 2    \\
    \hline
    B-1  & (break)          &                   \\
    B-2  & (break)          &                   \\
    B-3  & (break)          &                   \\
    \hline
    T2-1 & General          &                   \\
    T2-2 & General          & Blinky            \\
    T2-3 & General          & IMU/motors        \\
    T2-4 & General          & Radio control     \\
    T2-5 & General          & Functionality     \\
    T2-6 & Competition      & Competition, critique  \\
  \end{tabular}
\end{flushleft}

Notes:
%
\begin{enumerate}
\item There there may be a 6--10 day delay for the PCBs to be
  manufactured from the time of submission.  You will then need to
  book an assembly session in the SMT lab provided you have done the
  SMT lab induction.

\item Do not underestimate the blinky milestone.  It requires having a
  functional PCB with a microcontroller that turns on properly, a
  functional toolchain and the ability to download code into the
  microcontroller's flash memory.
\end{enumerate}

\section{Assessment}

The marks breakdown (max. 0x64) is:
%
\begin{flushleft}
  \begin{tabular}{ll}
    PCB submission & 0--0xa marks\\
    Blinky milestone  & 0x5 marks\\
    IMU/motor milestone  & 0x5 marks\\
    Radio control milestone  & 0x5 marks\\
    Functional assessment & 0--0x14 marks \\
    Board inspection & 0--0x1e marks \\
    Competition & 0--0xa marks \\
    Individual critique & 0--0xf marks \\
  \end{tabular}

\end{flushleft}

\subsection{Milestones}

There are five milestones.  To achieve the associated marks, they must
be demonstrated to a T.A. by the end of the lab for your allotted
stream.  If you need an exception to this, see Ben Mitchell with a
\emph{very} good reason.  The milestone requirements are:
%
\begin{description}
\item [Schematic review] Submit your A3 schematic on Learn for
  review.  Lose 10 marks if you miss the submission time.

\item [PCB submission] Submit your PCB design to Learn for
  manufacture.  To encourage early submission there is a sliding scale
  for marks depending on when the PCB is submitted, see table.  After
  week 6, there is a 10 mark penalty per week.  \textbf{NB, a rushed
    PCB design will cause you more grief, more PCB rework, and a lower
    mark for the inspection.}

  \begin{tabular}{llll}
    Week & Submission day & Cut-off time  & Mark \\ \hline
    5    & Monday       & 1.00 pm & 10 \\
    5    & Tuesday      & 1.00 pm & 9 \\
    5    & Wednesday    & 1.00 pm & 8 \\
    5    & Thursday     & 1.00 pm & 7 \\
    5    & Friday       & 1.00 pm & 6 \\
    6    & Monday       & 1.00 pm & 5 \\
    6    & Tuesday      & 1.00 pm & 4 \\
    6    & Wednesday    & 1.00 pm & 3 \\
    6    & Thursday     & 1.00 pm & 2 \\
    6    & Friday       & 1.00 pm & 1  \\
  \end{tabular}

\item [Blinky] Demonstrate that can blink an LED controlled by the SAM4S.

\item [IMU/motors] For the Wacky Hat, demonstrate output of IMU
  readings to a PC using USB CDC.  For the Wacky Racer, demonstrate
  control of the motors from a PC using USB CDC.

\item[Radio control] Demonstrate sending commands from the Wacky Hat
  to the Wacky Racer over a radio link.
\end{description}

\textbf{If you cannot show the functionality of a previous milestone
  during any assessment, you will fail that assessment and loose any
  marks from the previous milestone.}

\subsection{Functionality assessment}

Functionality requirements:
%
\begin{flushleft}
  \begin{tabular}{l|l}
    Wacky racer & Wacky hat \\ \hline \hline
    Blink LED                      & Blink LED \\
    Drive motors forward/backward  & Read from IMU \\
    Speed control of motors        & Calculate speeds from IMU \\
    Steering control               & Joystick control \\
    Receive radio message          & Send radio message \\
    Jumper selectable radio channel & Jumper selectable radio channel  \\
    Dies on bump                   & Plays sound on bump \\
    Low voltage indication         & Low voltage indication \\
  \end{tabular}
\end{flushleft}
%
Marks are allocated on how well things work.  Up to 5 bonus marks can
be awarded for extra functionality such as:
%
\begin{flushleft}
  \begin{tabular}{l|l}
    Wacky racer                & Wacky hat \\ \hline \hline
    Dastardly stuff            & Plays interesting sounds \\
    Sleep mode                 & Sleep mode \\
  \end{tabular}
\end{flushleft}

\subsection{Competition}

The competition is a race around an obstacle course.  Marks will be
awarded every time you pass over a Wacky Ramp in the correct order.
These ramps have an RFID card reader that will detect your Racer if
you have correctly fitted an RFID card.  The Wacky Ramps change colour
when they detect a Wacky Racer.

To be awarded any marks for the race:
%
\begin{enumerate}
\item Your vehicle must stop for at least 5\,s if the bumper is hit.

\item Your vehicle must be controlled by motions of the Wacky hat
  sitting on someone's head.
\end{enumerate}

\subsection{PCB inspection}

This is assessed after the competition.  The categories are:
%
\begin{enumerate}
\item Layout (component placement etc.)
\item Construction (tidiness, rework, etc.)
\item Testability
\item Power supplies (routing, decoupling, etc.)
\end{enumerate}

\section{Technical stuff}

Read this section carefully.  There are clues as to how we mark your PCBs at the
end of the assignment.

\subsection{External components}

\subsubsection{Battery}

The battery we provide for the assignment is a 5-cell NiMh battery with a
\emph{nominal} voltage of \SI{6.0}{\volt}. This battery uses a standard RC servo
connector: 3 pin 0.1'' (pin 1 GND, pin 2 5V, pin 3 NC). We suggest connecting
both the first and third pins to ground to allow the battery to be plugged in
in both orientations. The 461 Altium library has a component named
`Battery\_HEADER\_3pin' that is suitable to use.

\subsubsection{Radio}

The nRF24 module we provide is actually a tiny PCB with all of the high
frequency analogue components populated for you. This module breaks out the SPI
communication pins, the power supply pins, and two signal pins that you will
need to connect to your microcontroller. The CE and IRQ pins can both go to
general PIO pins while the SPI pins (MOSI, MISO, SCLK, CSN) need to be connected
to the SAM4S SPI peripheral.

As this radio is ultimately an analogue circuit and any noise on the power
supply can affect the signal quality, we recommend using a separate 3V3
regulator and using a low pass filter to provide the best power.

\begin{figure}[h]
  \centering
  \begin{circuitikz}
    \draw (-1, 0) node[left] {\SI{3.3}{\volt}} to[R=\SI{1}{\ohm}, o-] (2, 0)
    to[C=\SI{10}{\micro\farad}, *-*] (2, -2); 
    
    \draw (-1, -2) node[left] {GND} to[short, o-] (2, -2); 
    \draw (2, 0) to[short] (4, 0); 
    \draw (2, -2) to[short] (4, -2); 
    \draw (6, 0.5) -- (4, 0.5) -- (4, -2.5) -- (6, -2.5);
    \node[right=0.2] at (4, 0) {VCC}; 
    \node[right=0.2] at (4, -2) {GND}; 
    \node at (6, -1) {nRF24};
  \end{circuitikz}
\end{figure}

\subsubsection{LED Tape}

The LED tape is a string of WS2812 LEDs connected in a line. These LEDs use a
clever mechanism to pass the RGB data down the string. They are connected in
series like:

\begin{figure}[h]
  \centering
  \begin{circuitikz}
    
    \draw (0, 0) node[left] {\SI{5}{\volt}} to[short, o-] (13, 0);
    \draw (0, -4) node[left] {GND} to[short, o-] (13, -4);

    \draw (1, -1) rectangle (4, -3);
    \draw (5, -1) rectangle (8, -3);
    \draw (9, -1) rectangle (12, -3);

    \draw (0, -2) node[left] {DIN} to[short, o-] (1, -2) node[right] {DIN};
    \draw (4, -2) node[left] {DOUT} -- (5, -2) node[right] {DIN};
    \draw (8, -2) node[left] {DOUT} -- (9, -2) node[right] {DIN};
    \draw (12, -2) node[left] {DOUT} -- (13, -2);

    \draw (2.5, 0) -- (2.5, -1) node[below] {VCC};
    \draw (6.5, 0) -- (6.5, -1) node[below] {VCC};
    \draw (10.5, 0) -- (10.5, -1) node[below] {VCC};

    \draw (2.5, -4) -- (2.5, -3) node[above] {GND};
    \draw (6.5, -4) -- (6.5, -3) node[above] {GND};
    \draw (10.5, -4) -- (10.5, -3) node[above] {GND};

  \end{circuitikz}
\end{figure}

This means you will need to provide a three pin header (0.1" standard header)
with the pinout: pin 1 \SI{5}{\volt}, pin 2 signal, pin 3 ground. Each
individual LED has a maximum supply current of \SI{60}{\milli\ampere}
(\SI{20}{\milli\ampere} per red, green, blue channel). We will provide up to
half a metre of LED tape to each car or hat, giving a maximum number of 30 LEDs
to be driven.

\subsubsection{Bumper}

The provided bumper senses the contact through a simple limit switch. This
switch is normally open and on contact will close.

\begin{figure}[h]
  \centering
  \begin{circuitikz}
    
    \draw (0, 0) to[short, o-*] (2, 0) to[switch] (2, -2) node[ground]{};
    \draw (2, 0) to[R] (2, 2) node[vcc]{\SI{3.3}{\volt}};

    \draw[blue, dashed] (1.5, -0.5) rectangle (2.5, -1.5);
    \node[blue, right] at (2.5, -1) {limit switch};

  \end{circuitikz}
\end{figure}

Note that the pullup resistor shown could simple be the internal pullup resistor
on a PIO pin. The connector for the limit switch should be a simple 2 pin 0.1"
header. 

\subsubsection{Buzzer}

The buzzers supplied are passive piezo-electric devices. Applying a voltage
across the two terminals causes the element to deform. Applying an alternating
current to the device generates an audible tone. The larger the applied voltage
differential, the louder the tone becomes. There are plenty of example circuits
for piezo buzzers available online.

\subsubsection{Motors}

The motors available in the provided chassis are \SI{6}{\volt} DC motors. These
have a low DC resistance and will take as much current as the DRV8833 motor
driver can supply. You need to add connectors for the motors, either 2 pin 0.1"
headers or screw terminals are suggested.

\subsection{Version control}

Use version control for everything, or else!  Learning git is frustrating but is
a skill you will not regret.

Your group leader should create a forked copy of the wacky-racers git project
and then add the other group members to the project.  This can be done by:

\begin{enumerate}
\item Go to \url{https://eng-git.canterbury.ac.nz/wacky-racers/wacky-racers}

\item Click `Fork' button.  This will create a copy of the main repository for the project.

\item Click on the `Settings' menu then click the `Expand' button for
`Sharing and permissions'.  Change `Project Visibility' to `Private'.

\item Click on the `Members' menu and add group members as Developers.

\item Using a bash terminal (or other useful shell), enter the command:

\lstset{language=bash}
\lstset{basicstyle=\ttfamily\small}
\lstset{keywordstyle=\color{black}\ttfamily}
\lstset{breaklines}

\begin{lstlisting}
  $ git clone https://eng-git.canterbury.ac.nz/your-userid/wacky-racers.git
\end{lstlisting}

If you do not want to have to enter your password for every git
push/pull operation, you should set up ssh-keys and use the git URL instead:

\begin{lstlisting}[breaklines]
  $ git clone git@eng-git.canterbury.ac.nz:your-userid/wacky-racers.git
\end{lstlisting}

\item Add a remote URL for the main repository.
%
\begin{lstlisting}[breaklines]
  $ cd wacky-racers
  $ git remote add upstream https://eng-git.canterbury.ac.nz/wacky-racers/wacky-racers.git
\end{lstlisting}
%
Again if you do not want to manually enter your password, you can use:
%
\begin{lstlisting}[breaklines]
  $ cd wacky-racers
  $ git remote add upstream git@eng-git.canterbury.ac.nz:wacky-racers/wacky-racers.git
\end{lstlisting}

\item If we add more demo code or tweak the instructions in the main
repository, you can get the updated stuff using:
%
\begin{lstlisting}[breaklines]
  $ git pull upstream master
\end{lstlisting}
\end{enumerate}

\subsection{Components}

\begin{enumerate}
\item We recommend that you use components in the ECE Altium library.
  These are stocked in the SMT lab.  For any other components you may
  require, see Scott Lloyd in the SMT lab.

\item The Wacky Racer batteries are Turnigy 5-cell 6\,V, 2300\,mAh,
  NiMH with a three pin JST connector.  To preserve the battery life
  it is imperative to not draw current when the battery voltage is
  below 5\,V.  Note, when fully charged, the battery voltage may be 7.5\,V.
\end{enumerate}

\subsection{Connectors}

\begin{enumerate}
\item USB micro or mini connector for debugging
\item 3 pin 0.1'' for LED tape (pin 1 5\,V, pin 2 signal, pin 3 ground)
\item 2 pin 0.1'' for bumper (pin 1 switch, pin 2 ground)
\item 10 pin IDE for serial wire debug
\item 3 pin JR battery connector (pin 1 GND, pin 2 VBAT, pin 3 GND)
\item motor connectors (for Racer)
\item connectors for dastardly stuff
\end{enumerate}

\subsection{Schematics}

\begin{enumerate}
\item Have a look at the
  \href{http://ecewiki.elec.canterbury.ac.nz/mediawiki/index.php/ENCE461_Altium_tutorial}{Altium
    tutorial on ecewiki}.

\item Have a read of the
  \href{http://ecewiki.elec.canterbury.ac.nz/mediawiki/index.php/Schematic_guidelines}{schematic
    guidelines on ecewiki}.

\item Add you and your partner's name and your group number to the
  title block on your schematic.

\item Save PDF files of your schematics in your source repository.
  \textbf{Note, when debugging your PCBs, we will not help you until
    you show us your printed A3 schematic}.

\item We bet that you will not have enough test points to clip an oscilloscope
  probe to.  Do not think you can hold the probe tip against an MCU pin.  Ensure
  you give a meaningful name to the test point in its comment field.  A ground
  test point is essential for an oscilloscope earth clip. Keep this clear of
  other test points since the clip may short against them.  You will probably
  require at least two ground points.

\item Checking the schematic is the most crucial part of the
  assignment.  If the schematic is wrong then your PCB will be wrong.
  So, schematics must be thoroughly checked by another person.

\item Consider fall-back options if you have a problem with your PCB.

  The IMU for the Wacky Hat is tiny and we \textbf{strongly recommend} that you
  provide an alternative connector for connecting the following IMU module:
  \href{https://www.aliexpress.com/item/SPI-IIC-MPU9250-MPU-9250-MPU-9250-9-Axis-Attitude-Gyro-Accelerator-Magnetometer-Sensor-Module-MPU9250/32216818498.html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}{MPU-9250 on AliExpress}

  Similarly for the Wacky Racer, in case the H-bridge fails, provide two
  three-pin servo connectors so that external Electronic Speed
  Controllers (ESC) can be used to drive the motors.

\item It would be useful to have a jumper or two connected to a PIO
  pin so that you can configure your board.  For example, if a jumper
  is in, use the joystick, otherwise use the IMU.

\end{enumerate}

\subsection{PCBs}

\begin{enumerate}
\item Your four-layer PCBs are going to be manufactured in batches.
  There is at least a week turnaround time to get the boards made.

\item It is important that you check footprints for parts they you
  create.  We will impose a 10\% penalty for each rerun of a PCB, say
  due to a footprint mistake.  Get your partner to check.

\item Turn of the test point designators and turn on comments instead. This lets
  you give them human readable names to make your lives easier.

\item PCB layouts must be thoroughly checked by another person.

\item A PCB track can blow faster than a fuse. So keep high current
  tracks fat and short.

\item Clearly mark the positive and negative battery connections on
  the silk screen.

\item Some of the chips can get hot so thermal considerations are
  required.  Follow the manufacturers' guidelines in the datasheets.

\item The switching regulators can interfere with the radios.

\item Use a design rule check to see if any of the following
  constraints are violated:
%
\begin{itemize}
\item Minimum trace width (0.15\,mm)
\item Minimum trace clearance (0.15\,mm)
\item Minimum via size (0.3\,mm hole, 0.6\,mm outer diameter)
\item Minimum hole size (0.3\,mm)
\item Minimum annular ring (0.1\,mm)
\end{itemize}
%
For every violation of one these rules, we will deduct 1\% from your
final mark.

\item Check the
  \href{http://ecewiki.elec.canterbury.ac.nz/mediawiki/index.php/PCB_checklist}{PCB
    checklist on ecewiki} before submission.
\end{enumerate}

\subsection{Assembly}

\begin{enumerate}
\item Finding shorts is extremely frustrating so maximise clearances
  and test for shorts before populating components.

\item Components can be put through the oven on the reverse side
  although heavy components may need to be glued.

\item Never assume where pin 1 is on an IC; check the datasheet.
  5--10\% of groups will get this wrong.

\end{enumerate}

\subsection{Software}

\begin{enumerate}
\item We highly recommend using a personal laptop with Linux installed if
  possible. A virtual machine running Linux on Windows is acceptable for this.
  You will need to check instructions on ecewiki for how to install the required
  toolchain. We advise against using the Windows Subsystem for Linux, rather it
  is much simpler to fix issues when you just use an actual Linux.

\item Development on Windows is now possible thanks to Philipp Hoff, however,
  neither MPH, nor Ben can help with debugging the Windows toolchain.

\item If you are not using version control for this you are foolish.

\item Inspect MPH's sample code.

\end{enumerate}

\subsection{Programming}

\begin{enumerate}
\item If you are trying to program the SAM4S for the first time and
  are feeling tired or impatient, then do something else.

\item For the first program, do not use batteries or a USB connection.
  The ST-Link adapter will provide 3.3\,V to the MCU.

\item Detailed instructions can be found at
  \url{http://ecewiki.elec.canterbury.ac.nz/mediawiki/index.php/Wacky_racers_software}.
\end{enumerate}

\subsection{Debugging}

\begin{enumerate}
\item Start running small programs (such as the provided demo
  programs) to test each feature separately.

\item An oscilloscope is your friend.

\item It is possible to use the GDB debugger but you need to know what
  you are doing, especially with optimised code.

\item Drawing a diagram of what you think is happening is highly recommended. A
simple circuit diagram or timing diagram will often help you realise what you
have missed and let you fix it without asking for help.

\end{enumerate}

\subsection{Possibly asked questions with answers}

\begin{itemize}
\item \emph{Why use the SAM4s MCU?}  For this application most MCUs
  would suffice, even an 8-bit AVR microcontroller.  To level the
  playing field, I have chosen a MCU most students would not have used
  before.  This is an ARM based MCU made by Atmel I have used this in
  a number of projects.  Indeed we used to teach this chip in ENCE361.
  There are many other similar MCUs made by different manufacturers
  such as the STM32 that would just as suitable.

\item \emph{Why use a four layer PCB?}  Come to lectures to find out!

\item \emph{Why use 7.2\,V NiMH batteries for the Wacky Racers?}
  These were a legacy of previous Wacky Racers.  They are also safer
  than lithium batteries with sleep-deprived students.

%% \item \emph{Why can't I program my device using Windows?} Due to
%%   various aspects of the Windows ecosystem, setting up a fully
%%   functional build environment is more complicated, will often vary
%%   from machine to machine, will often break filepaths, and will often
%%   cause bizarre compilation errors. Use at your own risk, we will not
%%   assist in debugging issues related to Windows.

\end{itemize}

\section{Assistance}

\begin{itemize}
\item Emails to the lecturers (except of a personal nature) will be
  quietly ignored.

\item Questions anwered on the ENCE461 Learn discussion page will be
  promptly answered.

\item All decisions regarding legality of your dastardly devices are
  at the whim of Ben Mitchell.  You can email Ben at
  \href{mailto://ben.mitchell@pg.canterbury.ac.nz}{ben.mitchell@pg.canterbury.ac.nz} if you wish to keep your ideas secret.

\item TAs will be available in the scheduled lab times.  Priority will
  be given to groups assigned to the current lab session. \textbf{We will
  only provide assistance to students who have a printed A3 schematic
  sheet in front of them and have already tried looking up the problem
  on \url{https://ecewiki.elec.canterbury.ac.nz}}.

\item Questions pertaining to Altium and surface mount rework will be
  answered by Scott Lloyd (SMT Lab technician) and Diego Ramirez
  (Electronics Lab technician).

\item Michael Hayes is really busy pulling all the string behind the
  scenes and so will only help with gnarly problems referred to by the
  TAs!

\end{itemize}

\end{document}

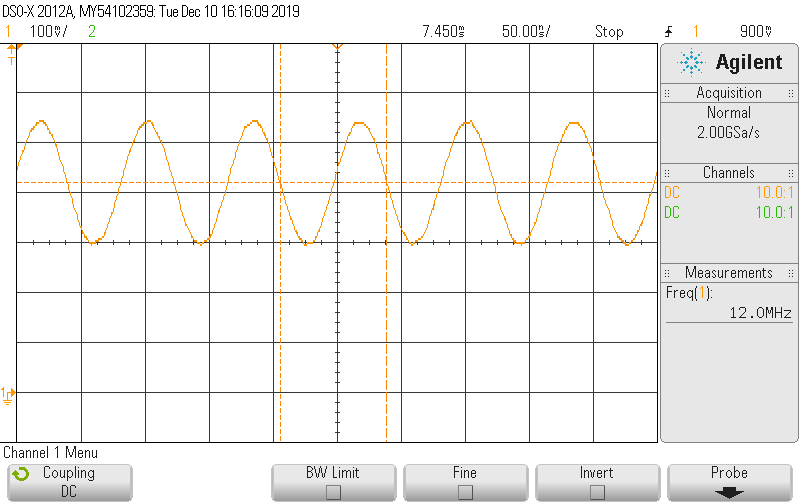
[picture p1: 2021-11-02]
doc/guide/figs/ClockSignal.png

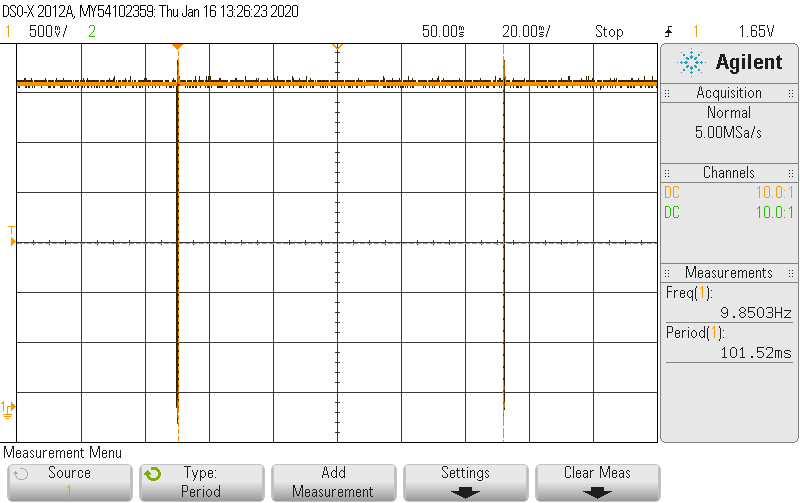
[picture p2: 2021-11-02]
doc/guide/figs/OpenOCDTimingGood.png

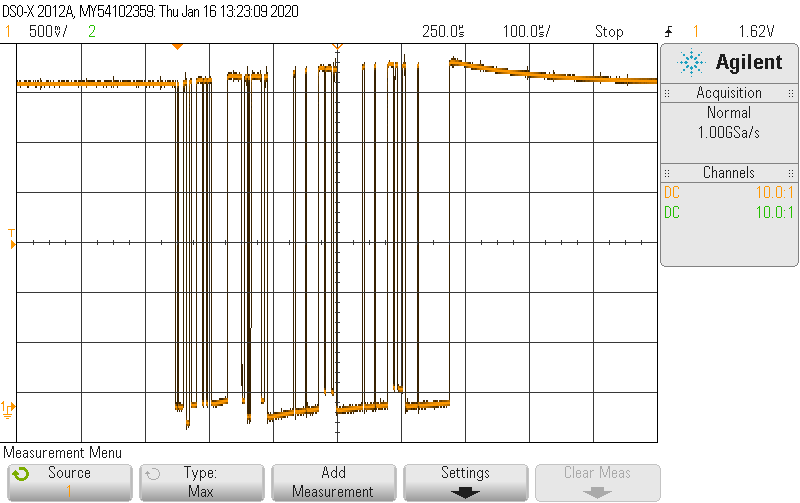
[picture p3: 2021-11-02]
doc/guide/figs/OpenOCDPollingGood.png

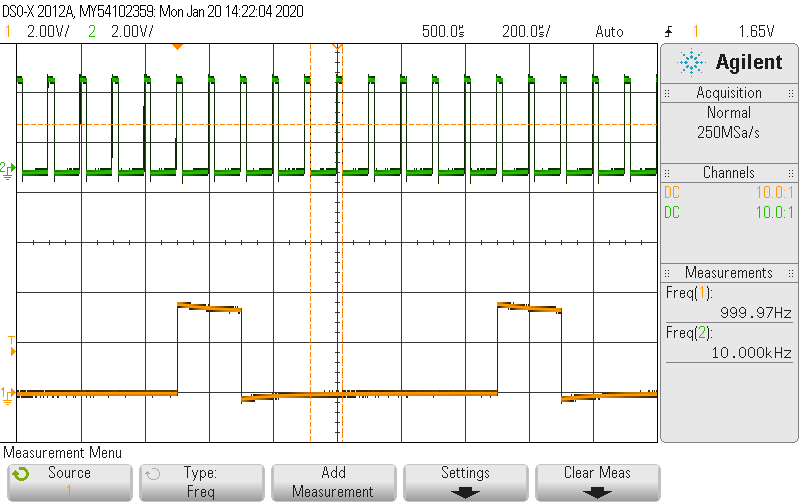
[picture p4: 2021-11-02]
doc/guide/figs/PWM_2.png

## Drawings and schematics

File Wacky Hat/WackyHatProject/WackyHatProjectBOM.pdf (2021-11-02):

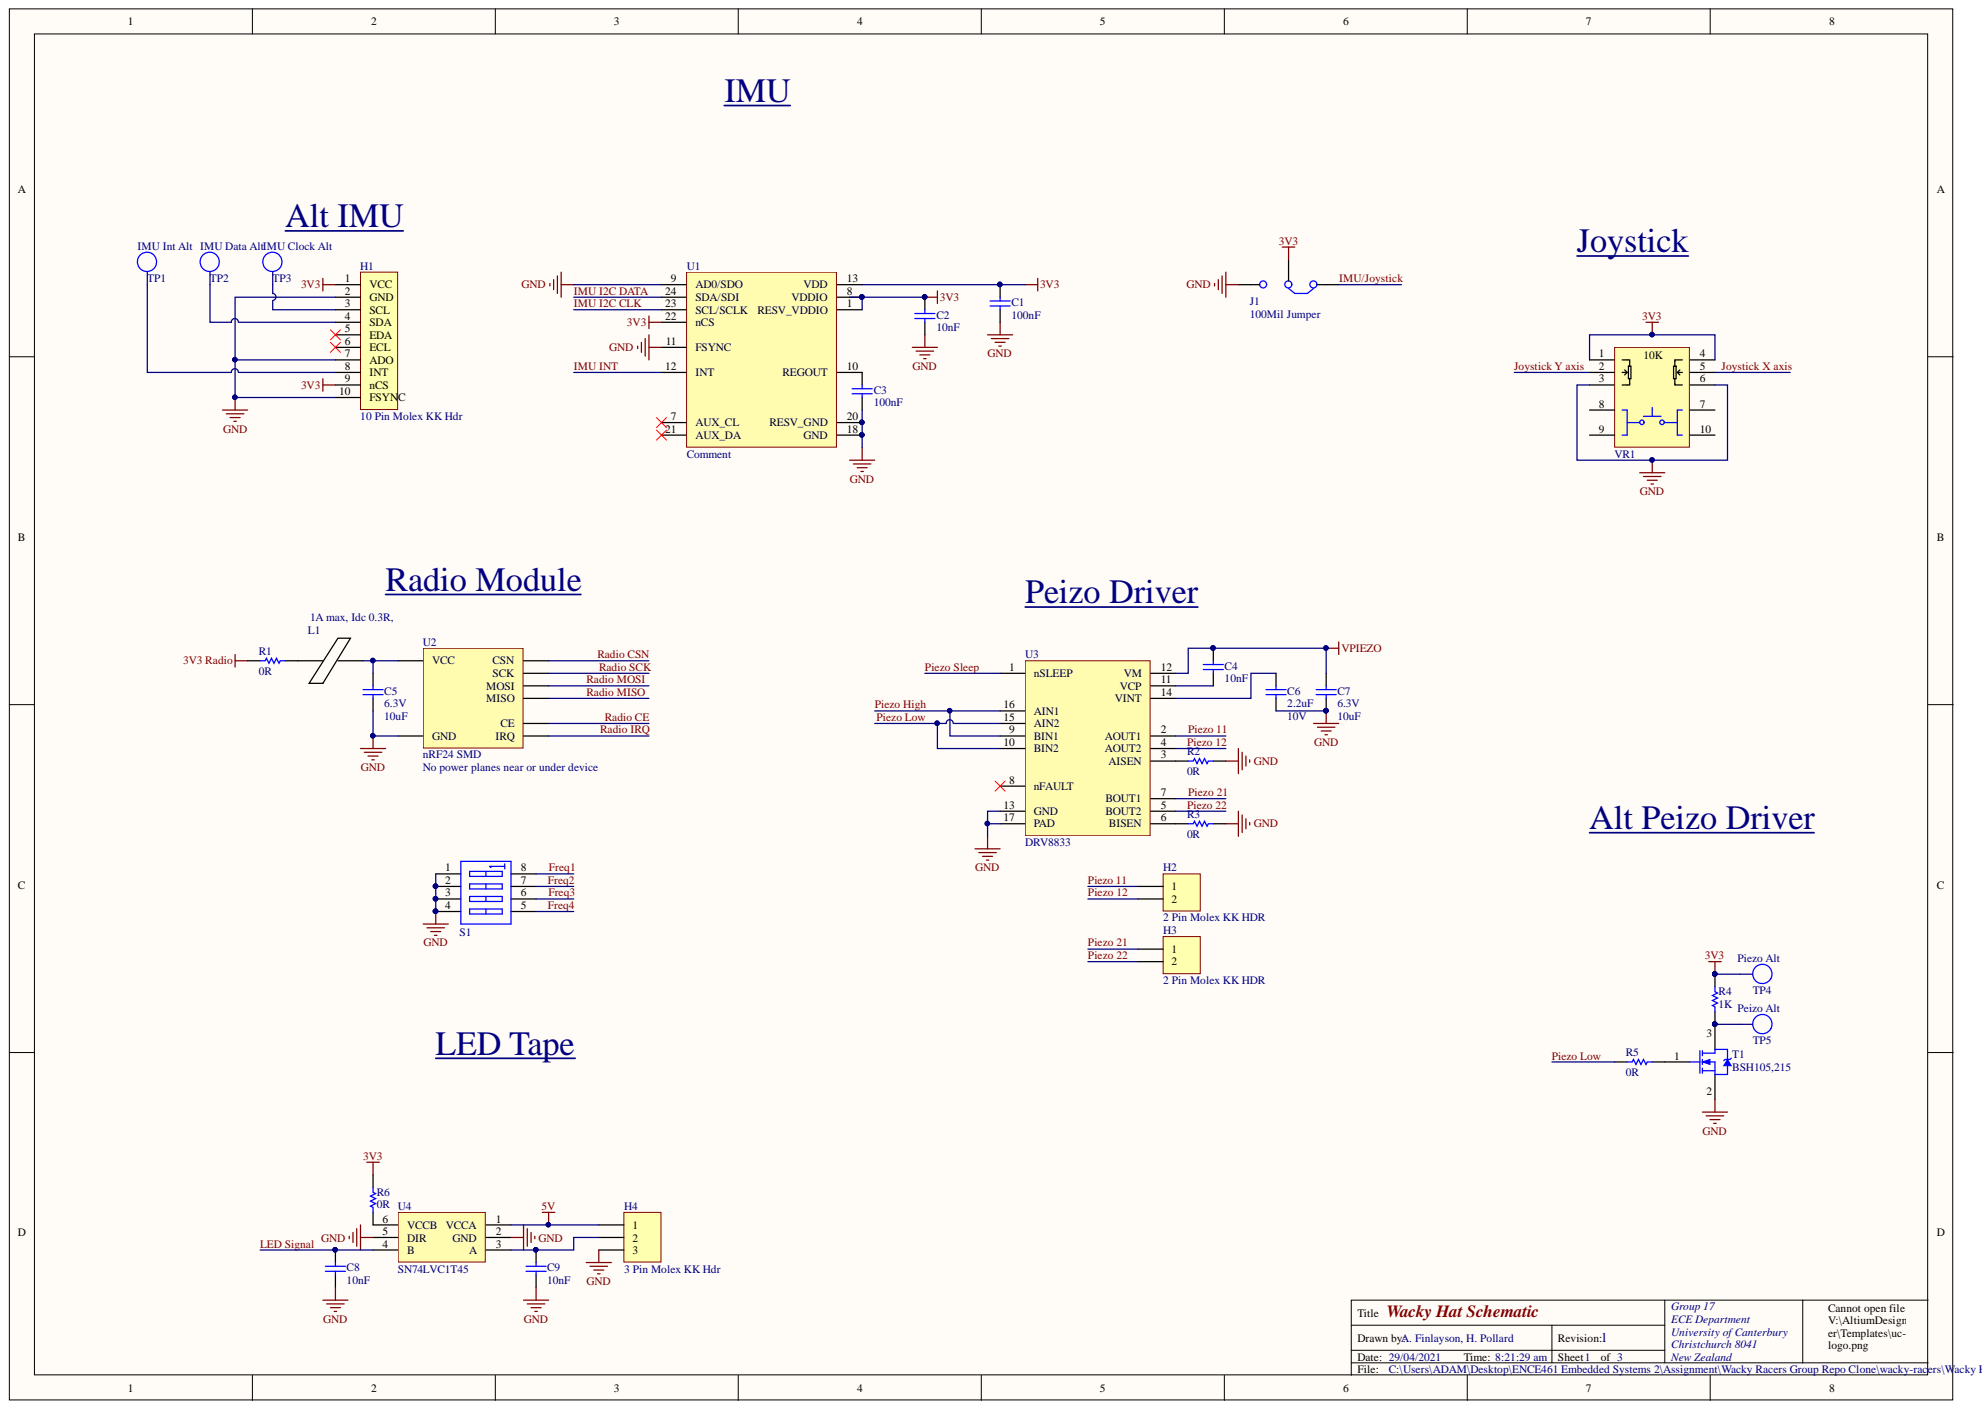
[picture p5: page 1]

10 Pin Molex KK Hdr

Radio Module 1A max, Idc 0.3R,

GND
nRF24 SMD
No power planes near or under device

Wacky Hat Schematic Title | Group 17 ECE Department University of Canterbury Christchurch 8041 New Zealand | Cannot open file V:\AltiumDesign er\Templates\uc-logo.png

Drawn by: A. Finlayson, H. Pollard | Revision:
Date: 29/04/2021 Time: 8:21:29 am | Sheet of 3

C:\Users\ADAM\Desktop\ENCE461 Embedded Systems 2\Assignment\Wacky Racers Group Repo Clone\wacky-racers\Wacky Hat\WackyHatProject\IMU_Radio.SchDoc

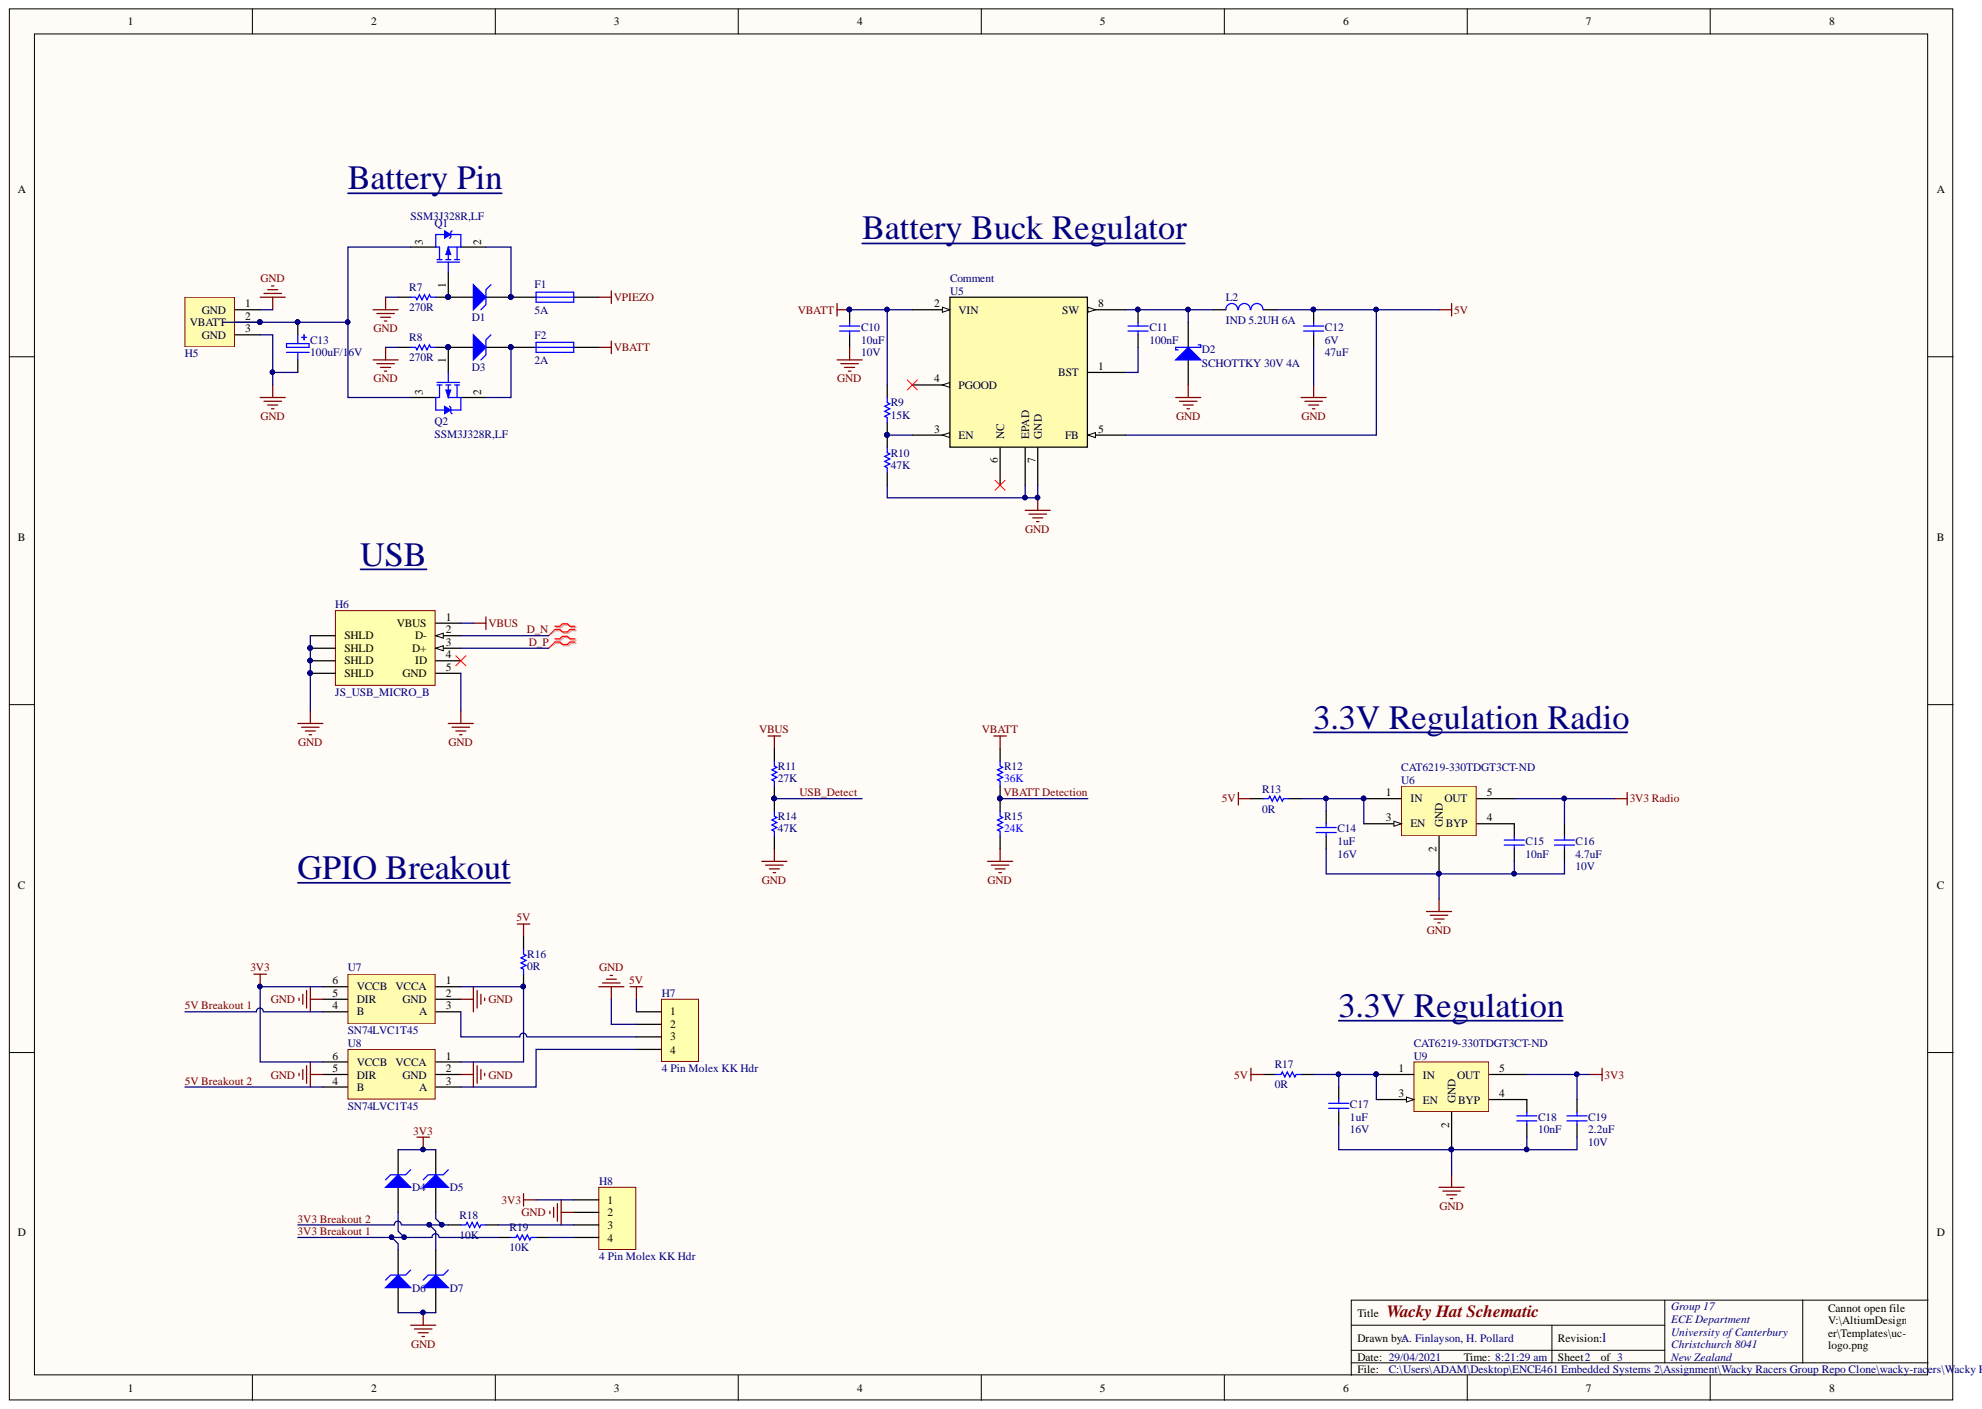
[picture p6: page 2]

C:\Users\ADAM\Desktop\ENCE461 Embedded Systems 2\Assignment\Wacky Racers Group Repo Clone\wacky-racers\Wacky Hat\WackyHatProject\Power_USB.SchDoc

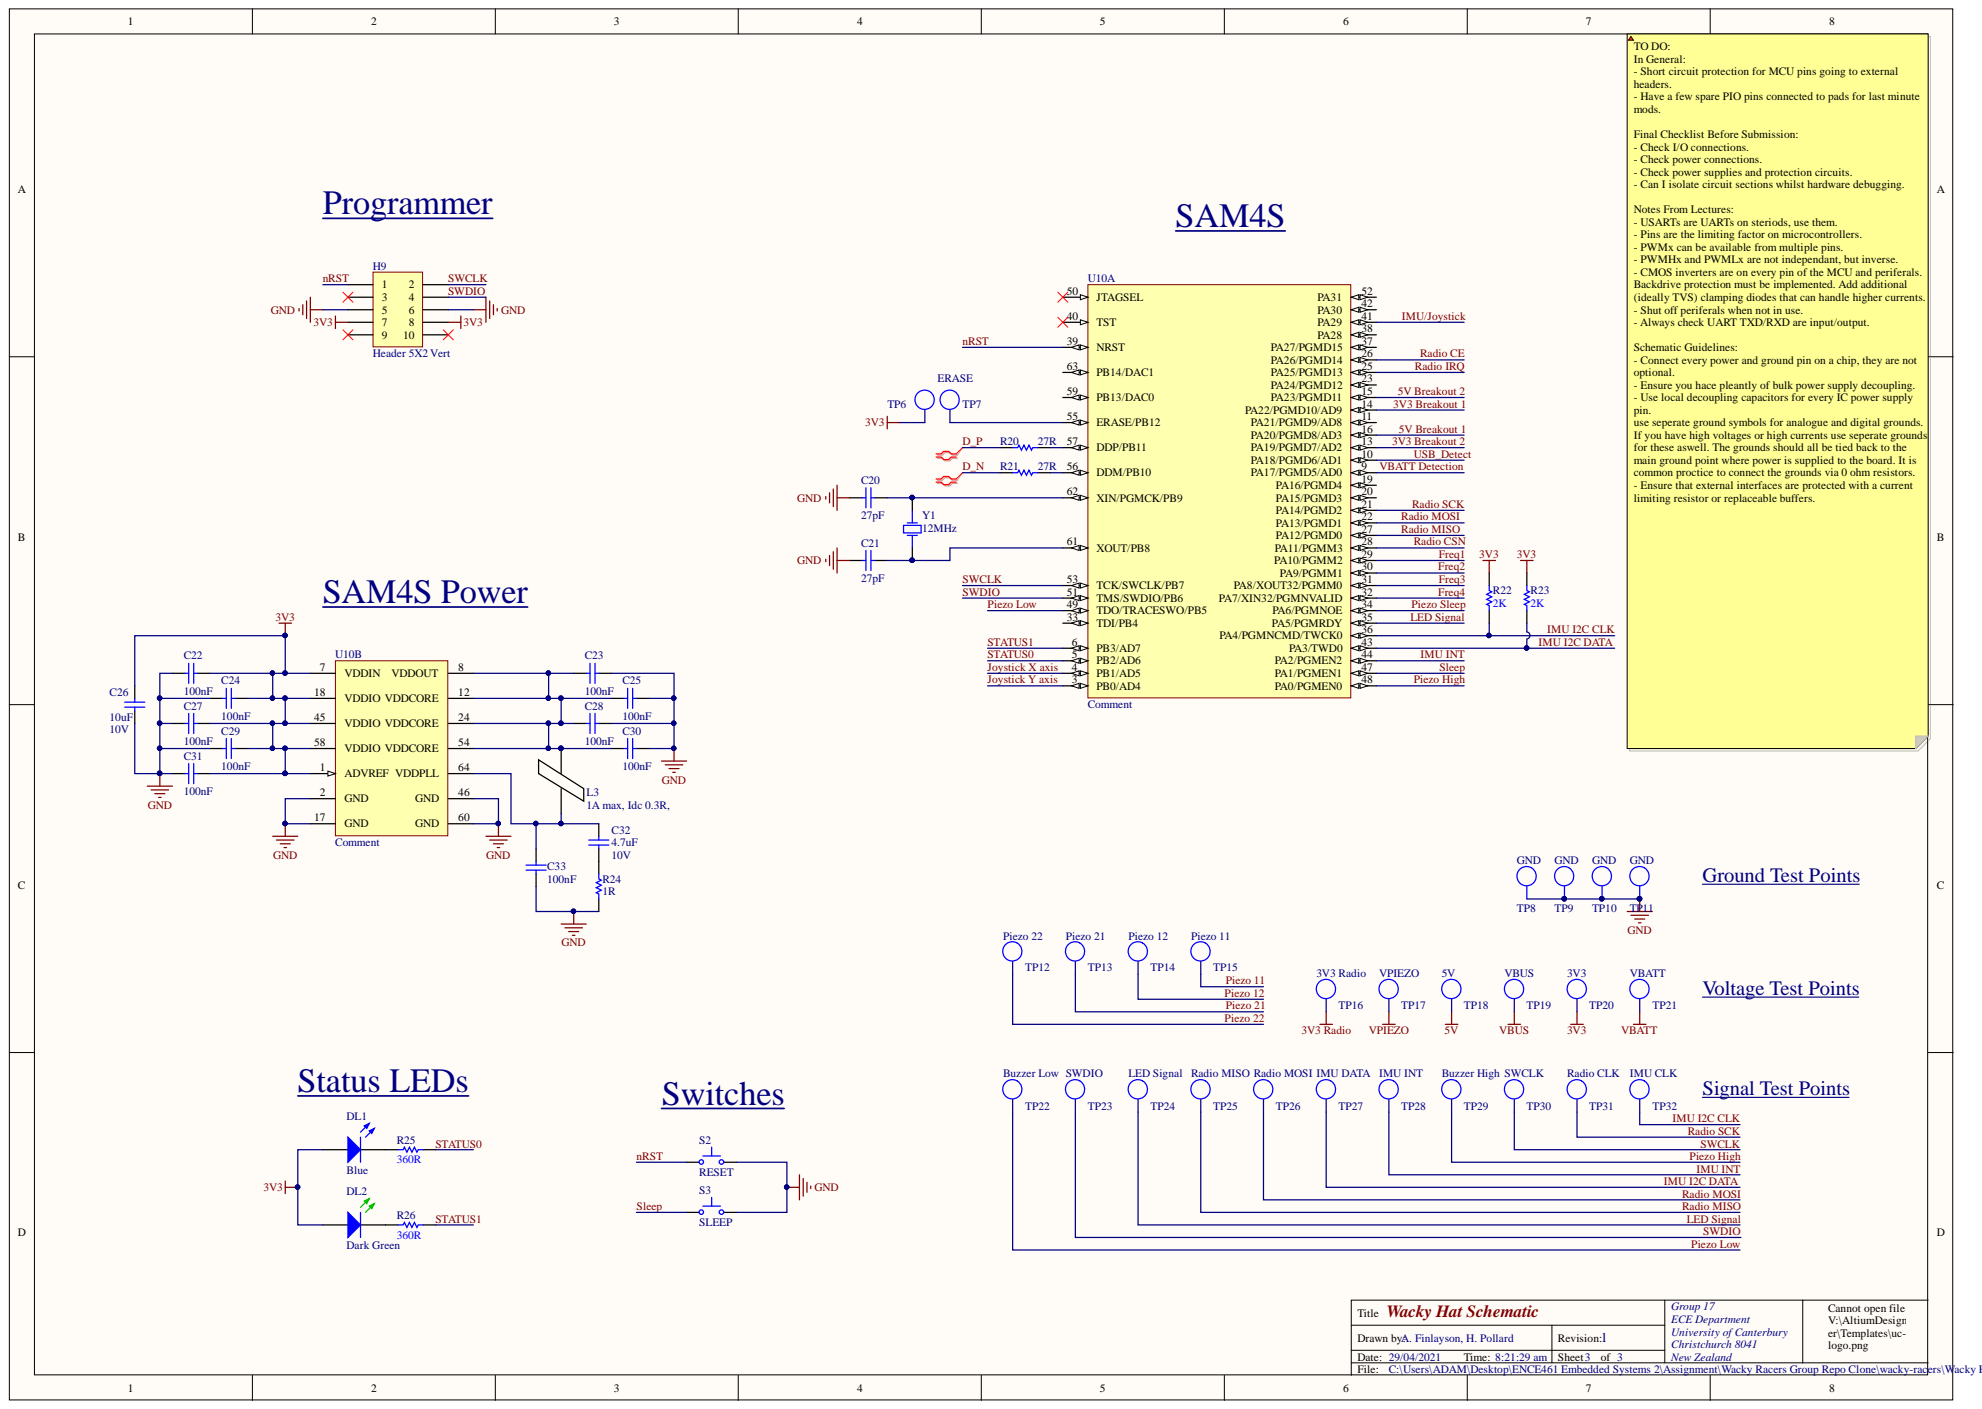
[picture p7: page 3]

In General:
- Short circuit protection for MCU pins going to external
headers.
- Have a few spare PIO pins connected to pads for last minute
mods.

Final Checklist Before Submission:
- Check I/O connections.
- Check power connections.
- Check power supplies and protection circuits.
- Can I isolate circuit sections whilst hardware debugging.

Notes From Lectures:
- USARTs are UARTs on steriods, use them.
- Pins are the limiting factor on microcontrollers.
- PWMx can be available from multiple pins.
- PWMHx and PWMLx are not independant, but inverse.
- CMOS inverters are on every pin of the MCU and periferals.
Backdrive protection must be implemented. Add additional
(ideally TVS) clamping diodes that can handle higher currents.
- Shut off periferals when not in use.
- Always check UART TXD/RXD are input/output.

Schematic Guidelines:
- Connect every power and ground pin on a chip, they are not
optional.
- Ensure you hace pleantly of bulk power supply decoupling.
- Use local decoupling capacitors for every IC power supply
pin.
use seperate ground symbols for analogue and digital grounds.
If you have high voltages or high currents use seperate grounds
for these aswell. The grounds should all be tied back to the
main ground point where power is supplied to the board. It is
common proctice to connect the grounds via 0 ohm resistors.
- Ensure that external interfaces are protected with a current
limiting resistor or replaceable buffers.

C:\Users\ADAM\Desktop\ENCE461 Embedded Systems 2\Assignment\Wacky Racers Group Repo Clone\wacky-racers\Wacky Hat\WackyHatProject\SAM4S_Piezo_LED.SchDoc

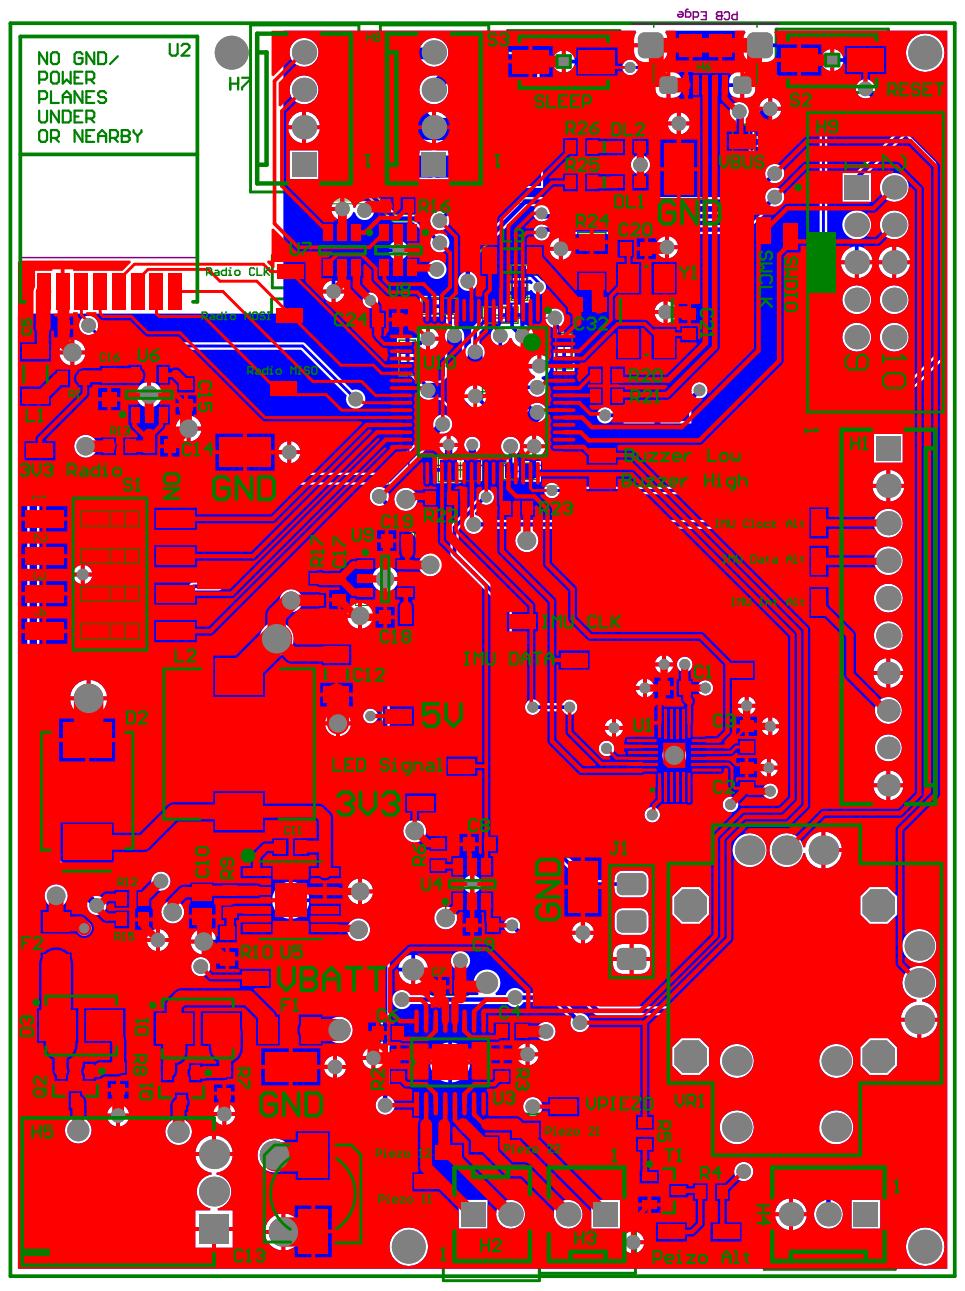
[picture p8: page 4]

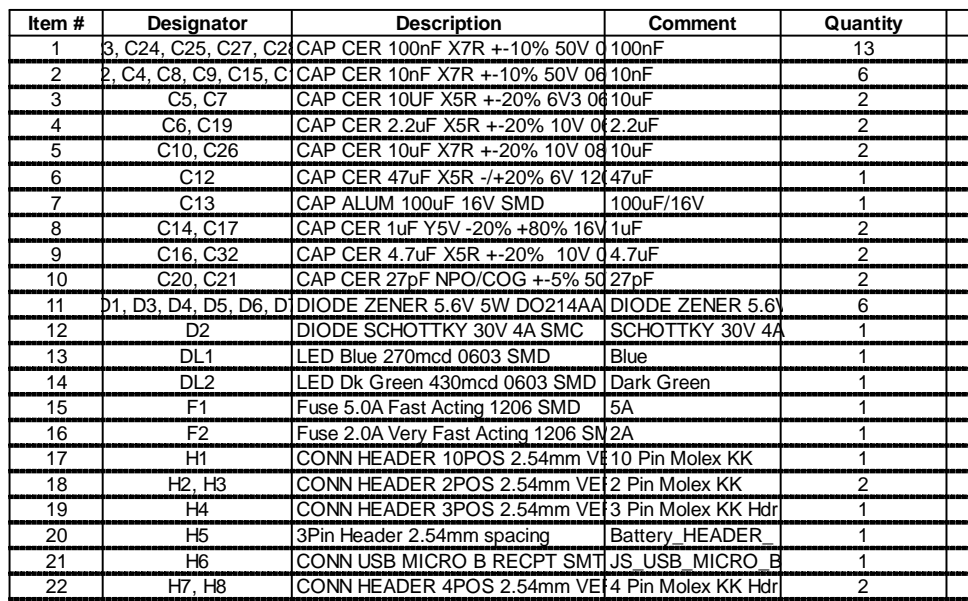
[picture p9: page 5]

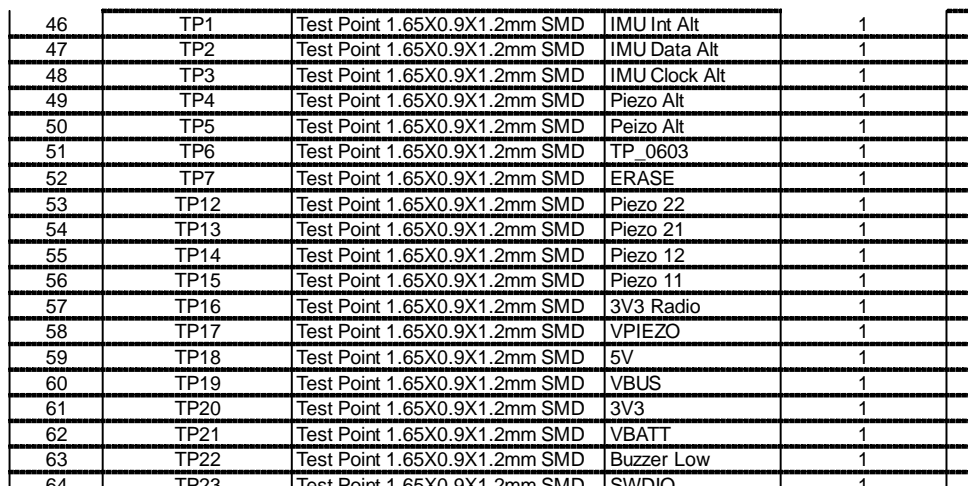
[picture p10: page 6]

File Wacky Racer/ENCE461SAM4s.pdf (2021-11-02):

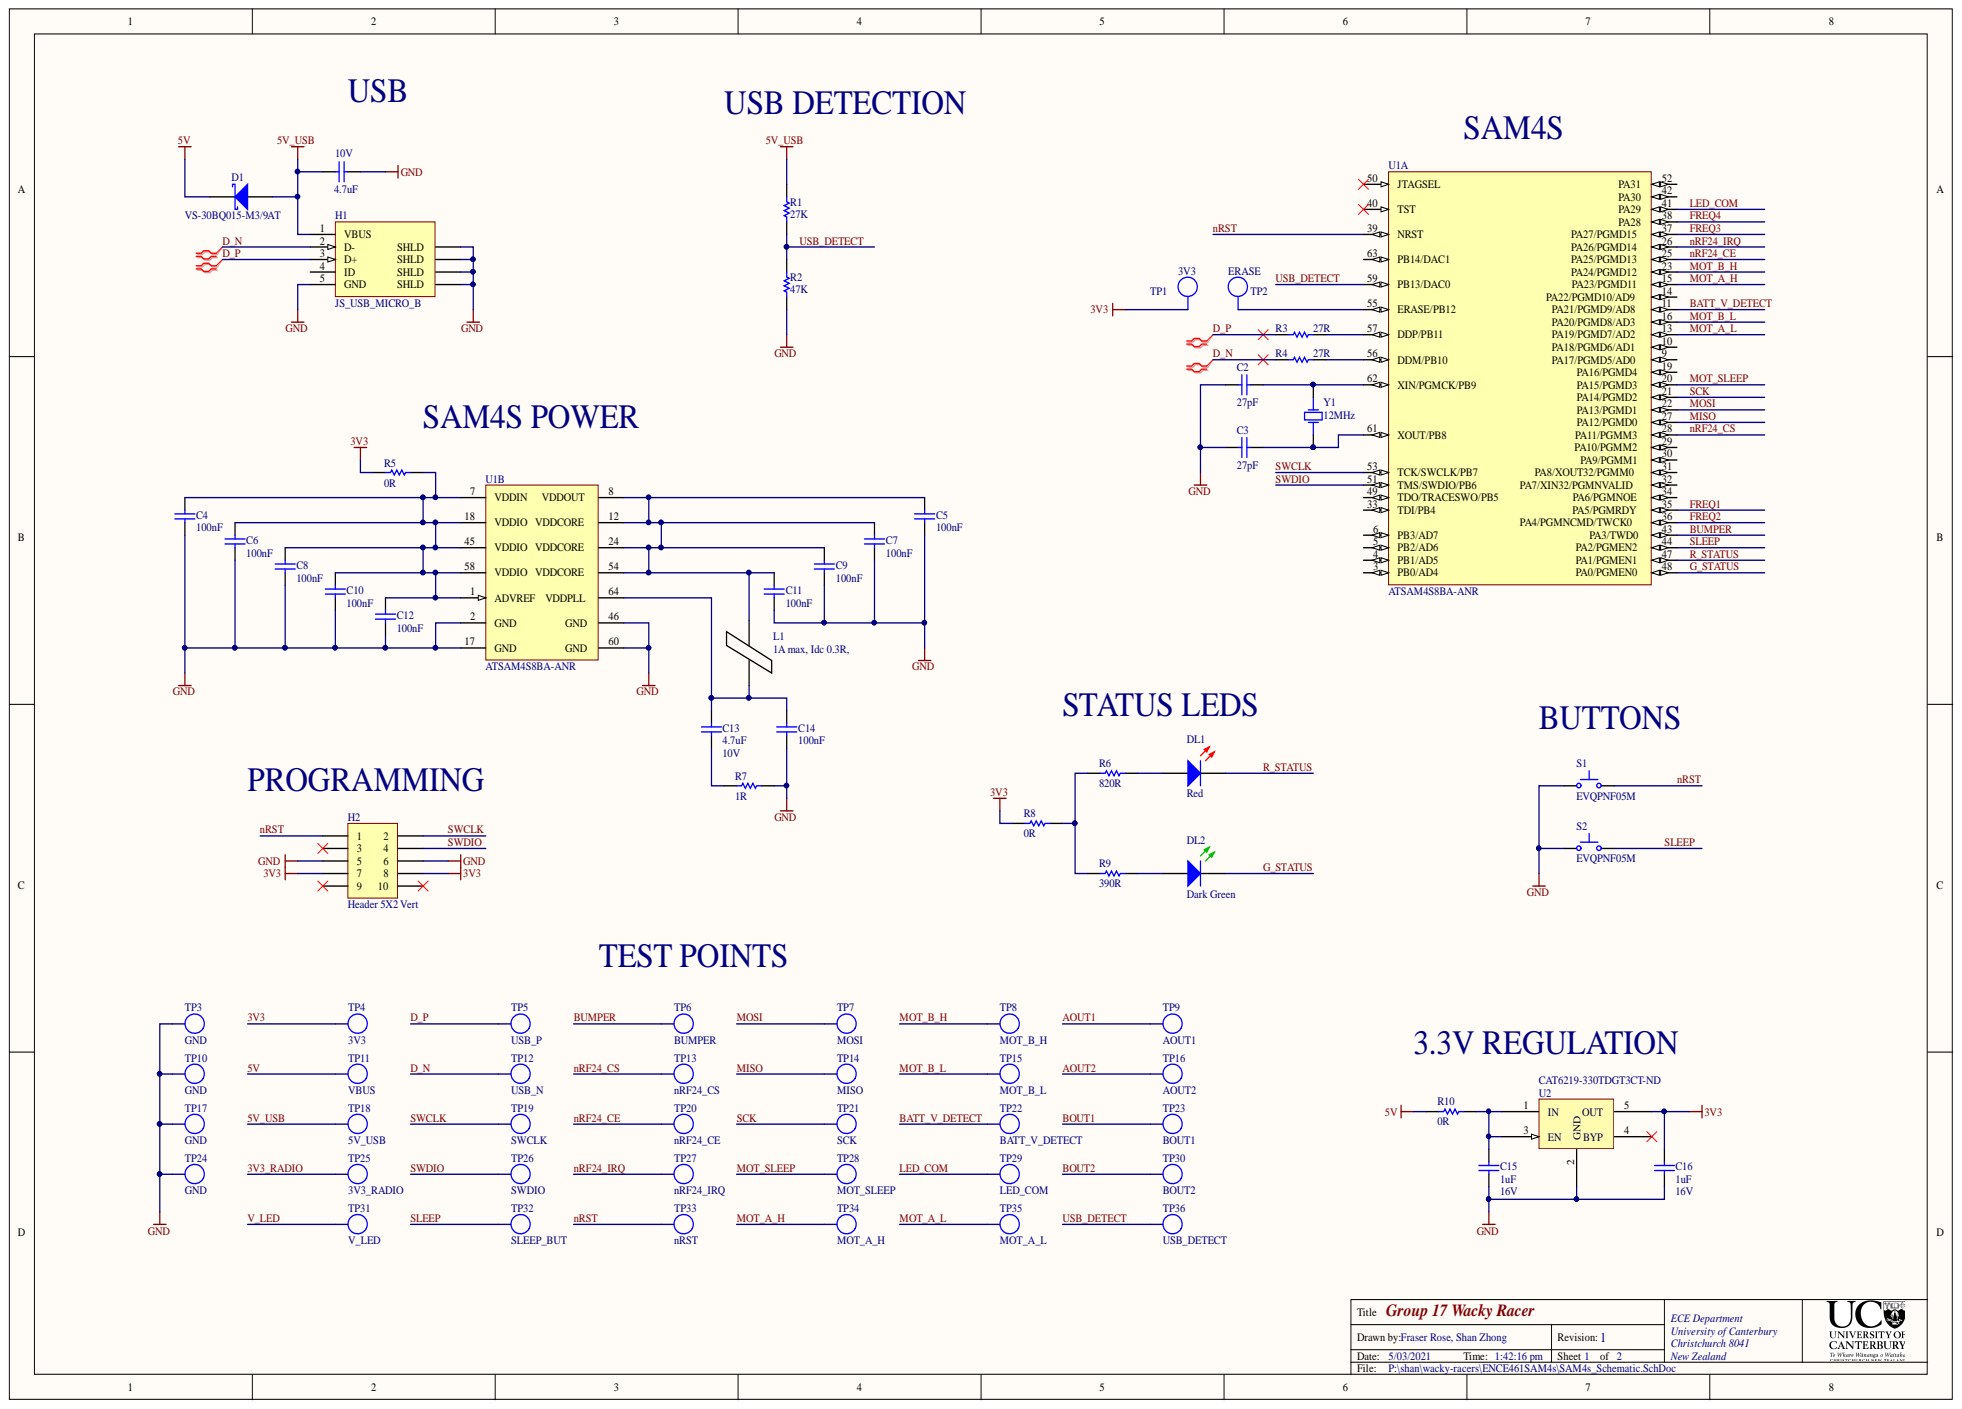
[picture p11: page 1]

Group 17 Wacky Racer Title | ECE Department University of Canterbury Christchurch 8041 New Zealand

Drawn by: Fraser Rose, Shan Zhong | Revision: 1
Date: 5/03/2021 Time: 1:42:16 pm | Sheet 1 of 2

P:\shan\wacky-racers\ENCE461SAM4s\SAM4s_Schematic.SchDoc

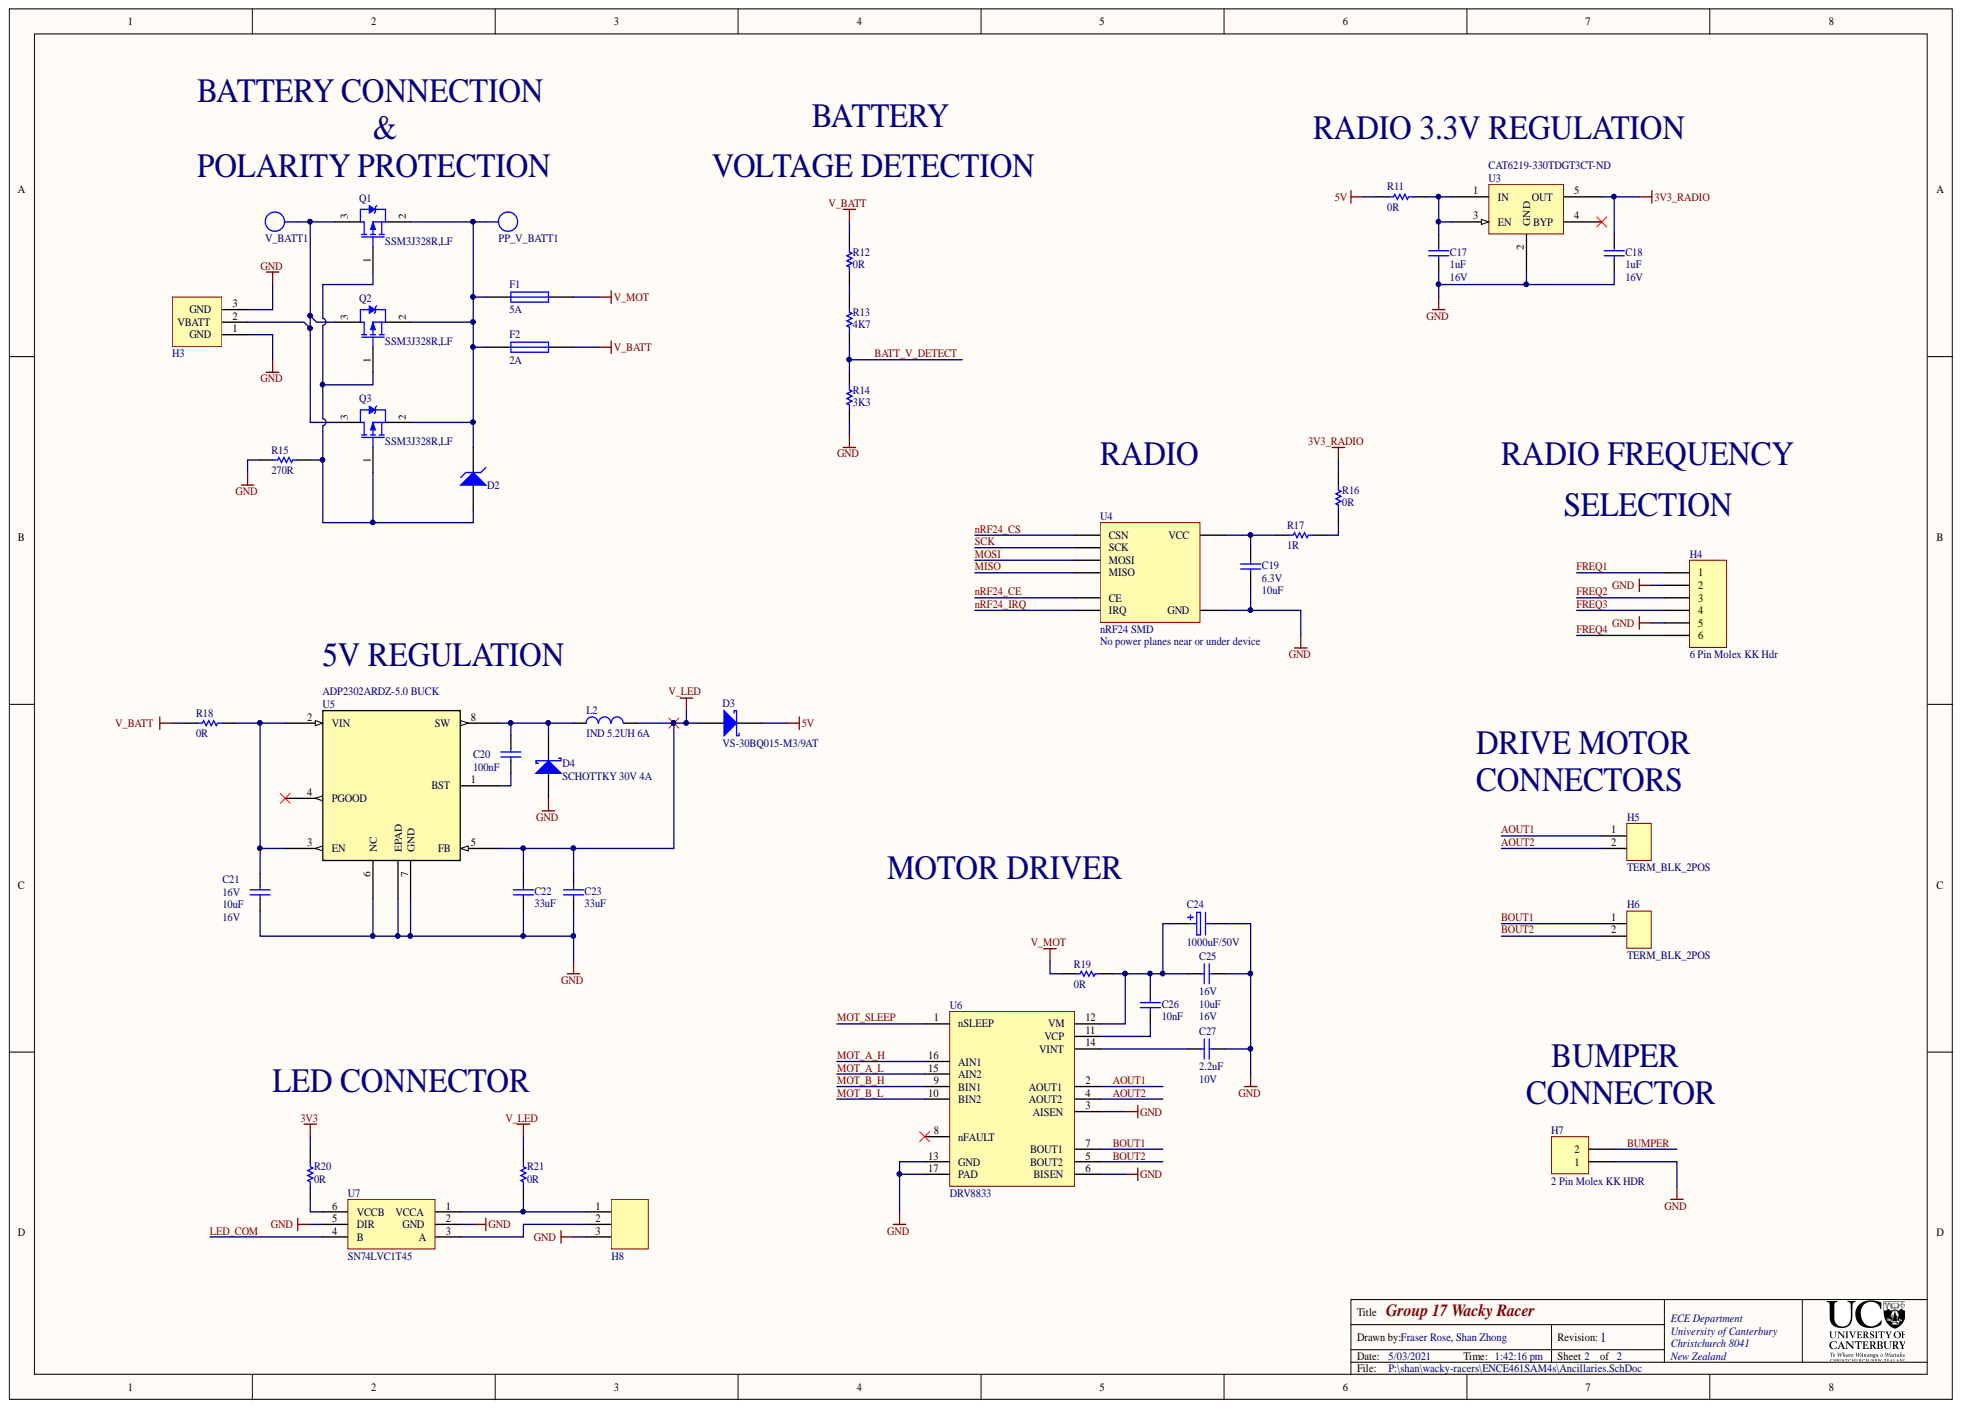
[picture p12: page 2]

IRQ
nRF24 SMD
No power planes near or under device

Group 17 Wacky Racer Title | ECE Department University of Canterbury Christchurch 8041 New Zealand

Drawn by: Fraser Rose, Shan Zhong | Revision: 1
Date: 5/03/2021 Time: 1:42:16 pm | Sheet 2 of 2

P:\shan\wacky-racers\ENCE461SAM4s\Ancillaries.SchDoc

# Board Stack Report

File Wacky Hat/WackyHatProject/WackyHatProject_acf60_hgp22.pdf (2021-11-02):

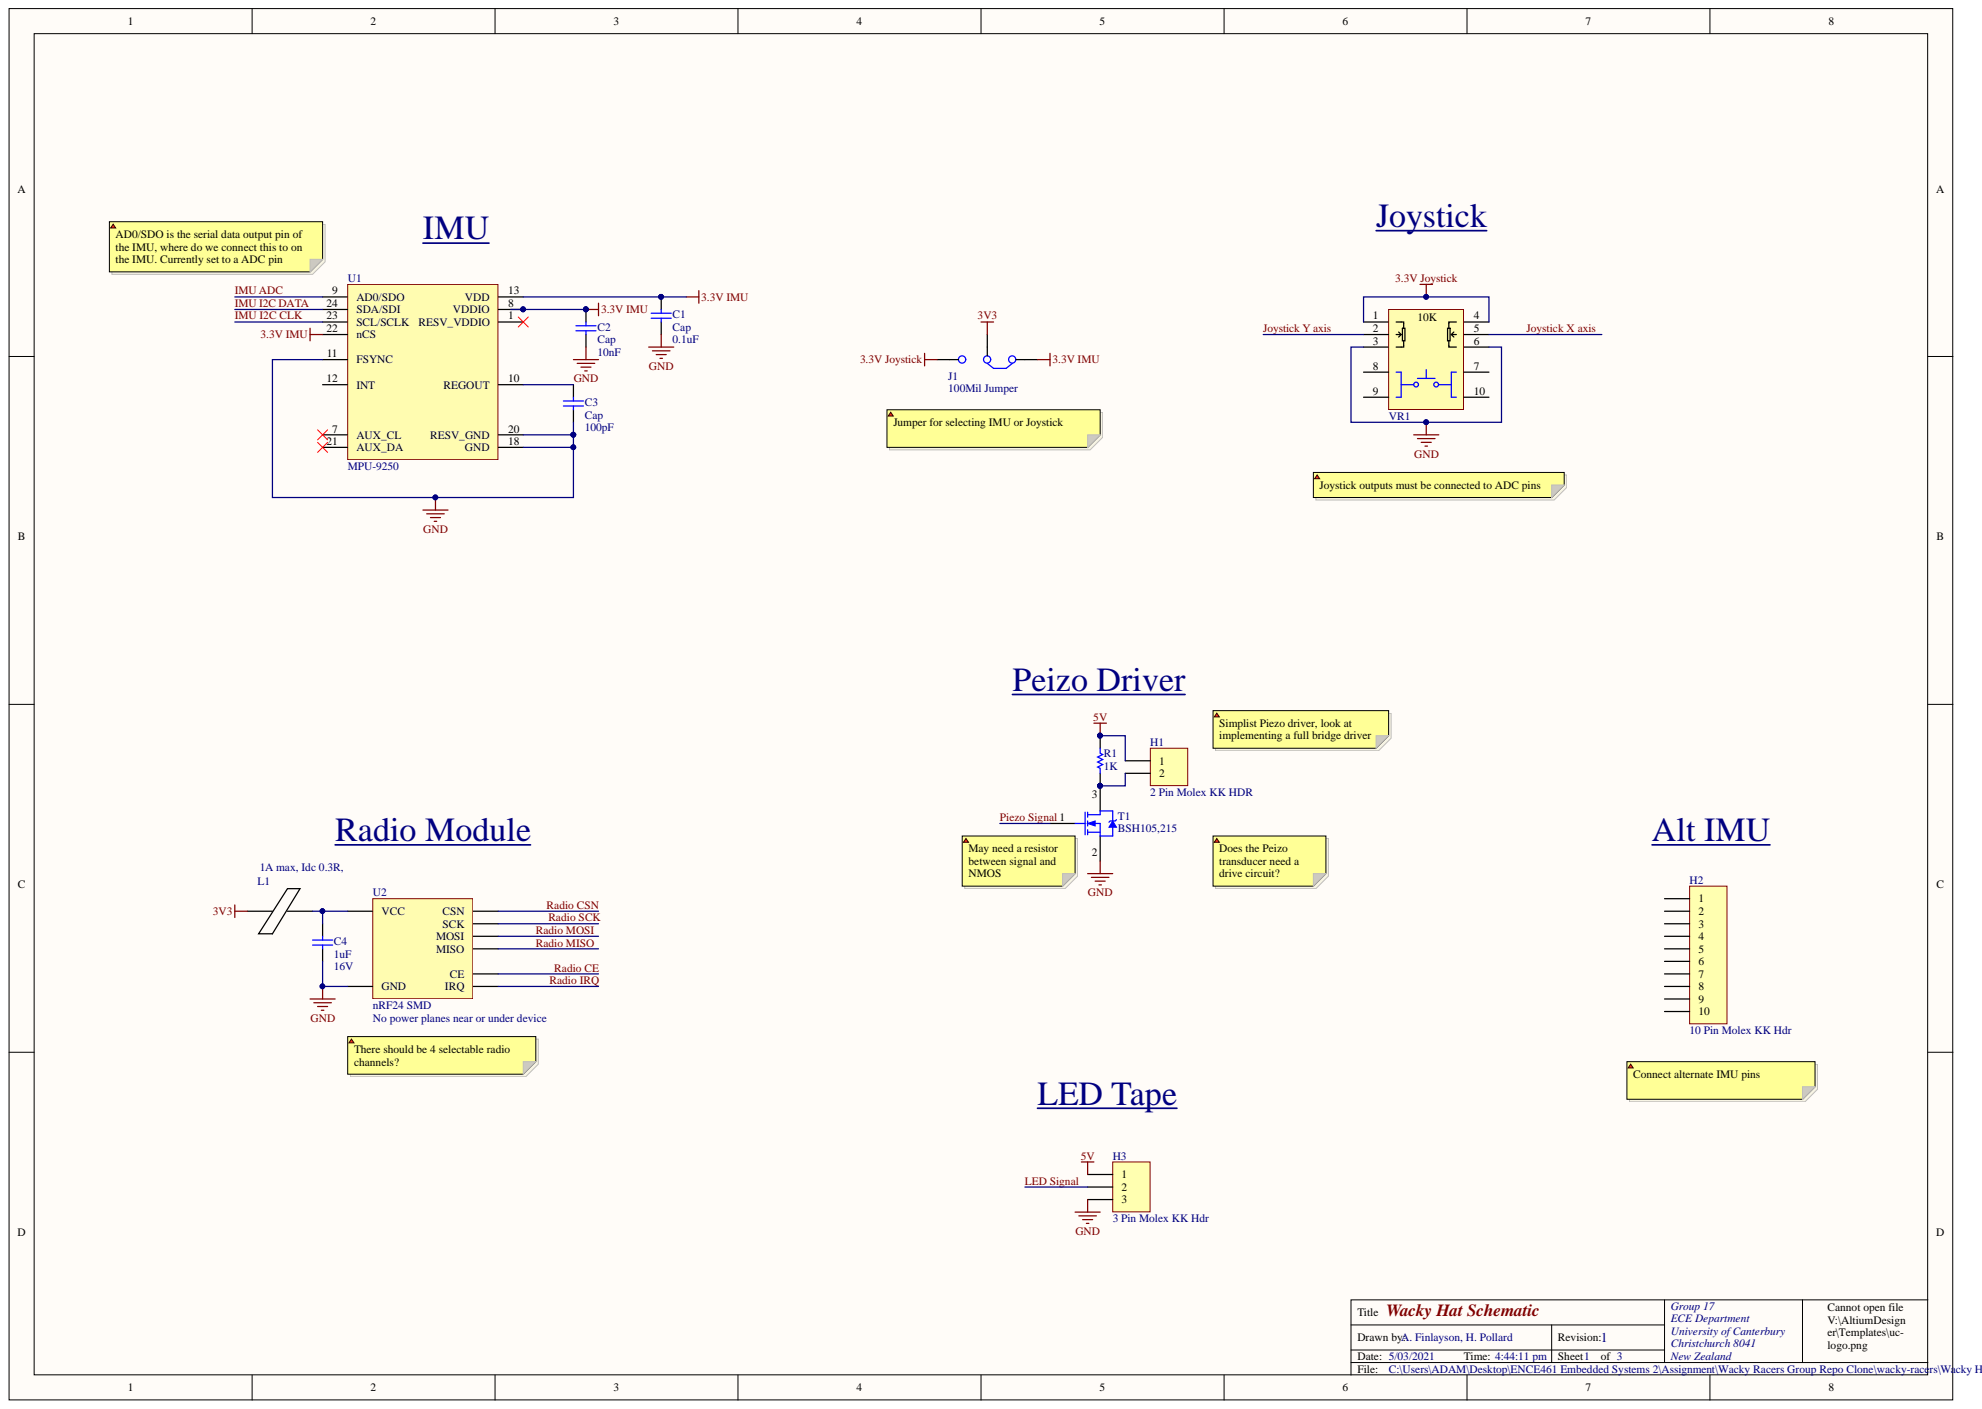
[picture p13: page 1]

AD0/SDO is the serial data output pin of
the IMU, where do we connect this to on
the IMU. Currently set to a ADC pin

Jumper for selecting IMU or Joystick

Joystick outputs must be connected to ADC pins

Simplist Piezo driver, look at
implementing a full bridge driver

Radio Module 1A max, Idc 0.3R,

GND
nRF24 SMD
No power planes near or under device

There should be 4 selectable radio
channels?

Connect alternate IMU pins

Wacky Hat Schematic Title | Group 17 ECE Department University of Canterbury Christchurch 8041 New Zealand | Cannot open file V:\AltiumDesign er\Templates\uc-logo.png

Drawn by: A. Finlayson, H. Pollard | Revision:
Date: 5/03/2021 Time: 4:44:11 pm | Sheet of 3

C:\Users\ADAM\Desktop\ENCE461 Embedded Systems 2\Assignment\Wacky Racers Group Repo Clone\wacky-racers\Wacky Hat\WackyHatProject\IMU_Radio.SchDoc

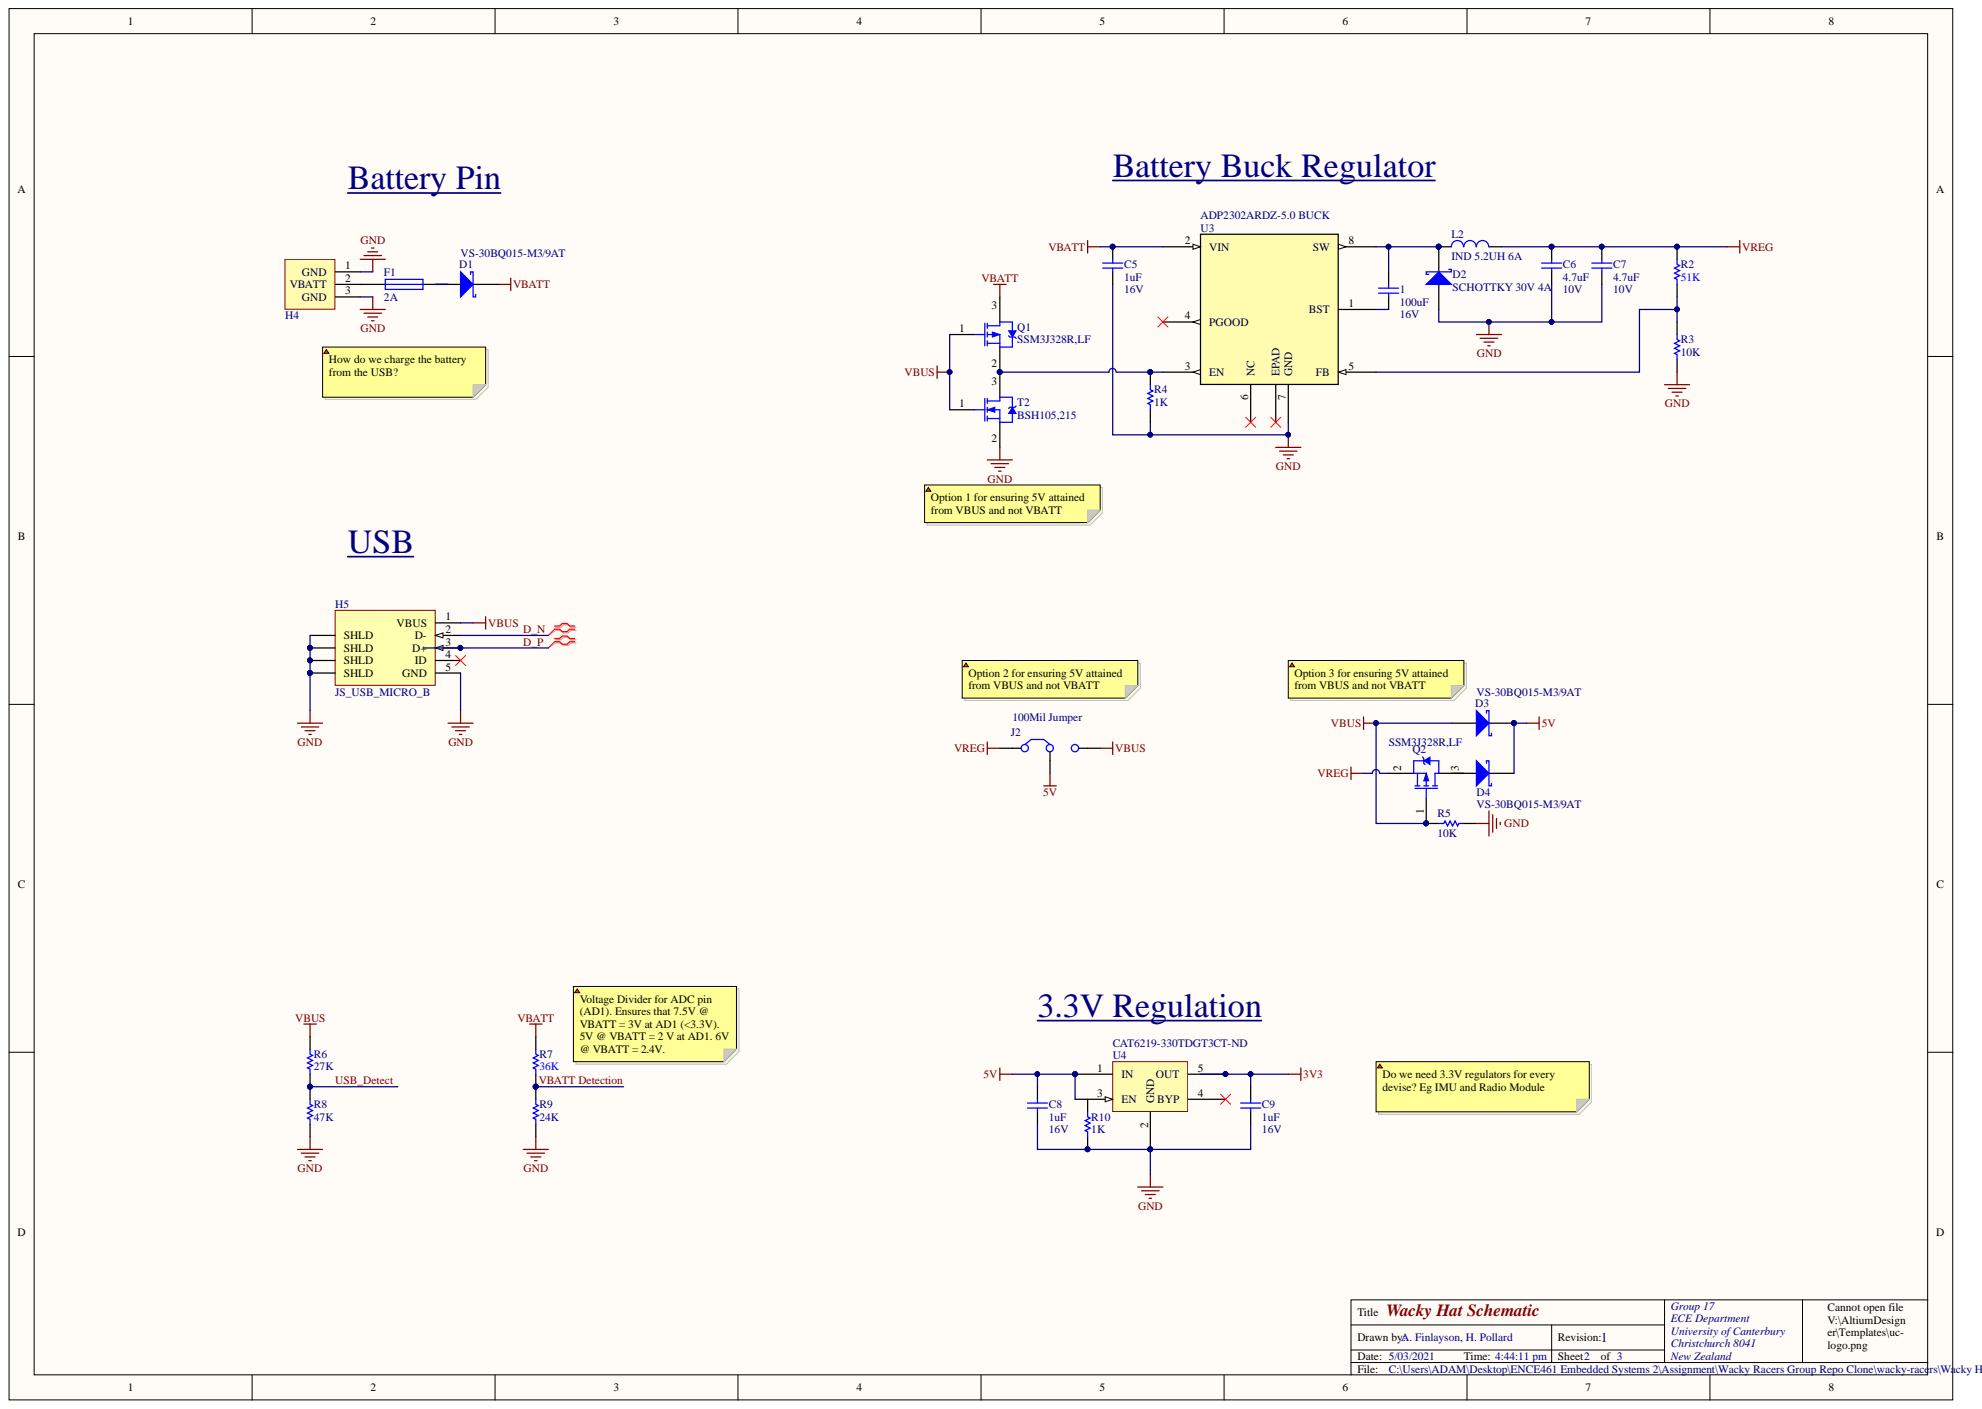
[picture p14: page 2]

How do we charge the battery
from the USB?

Option 1 for ensuring 5V attained
from VBUS and not VBATT

Option 2 for ensuring 5V attained

Option 3 for ensuring 5V attained

Voltage Divider for ADC pin
(AD1). Ensures that 7.5V @
VBATT = 3V at AD1 (<3.3V).
5V @ VBATT = 2 V at AD1. 6V
@ VBATT = 2.4V.

Do we need 3.3V regulators for every
devise? Eg IMU and Radio Module

C:\Users\ADAM\Desktop\ENCE461 Embedded Systems 2\Assignment\Wacky Racers Group Repo Clone\wacky-racers\Wacky Hat\WackyHatProject\Power_USB.SchDoc

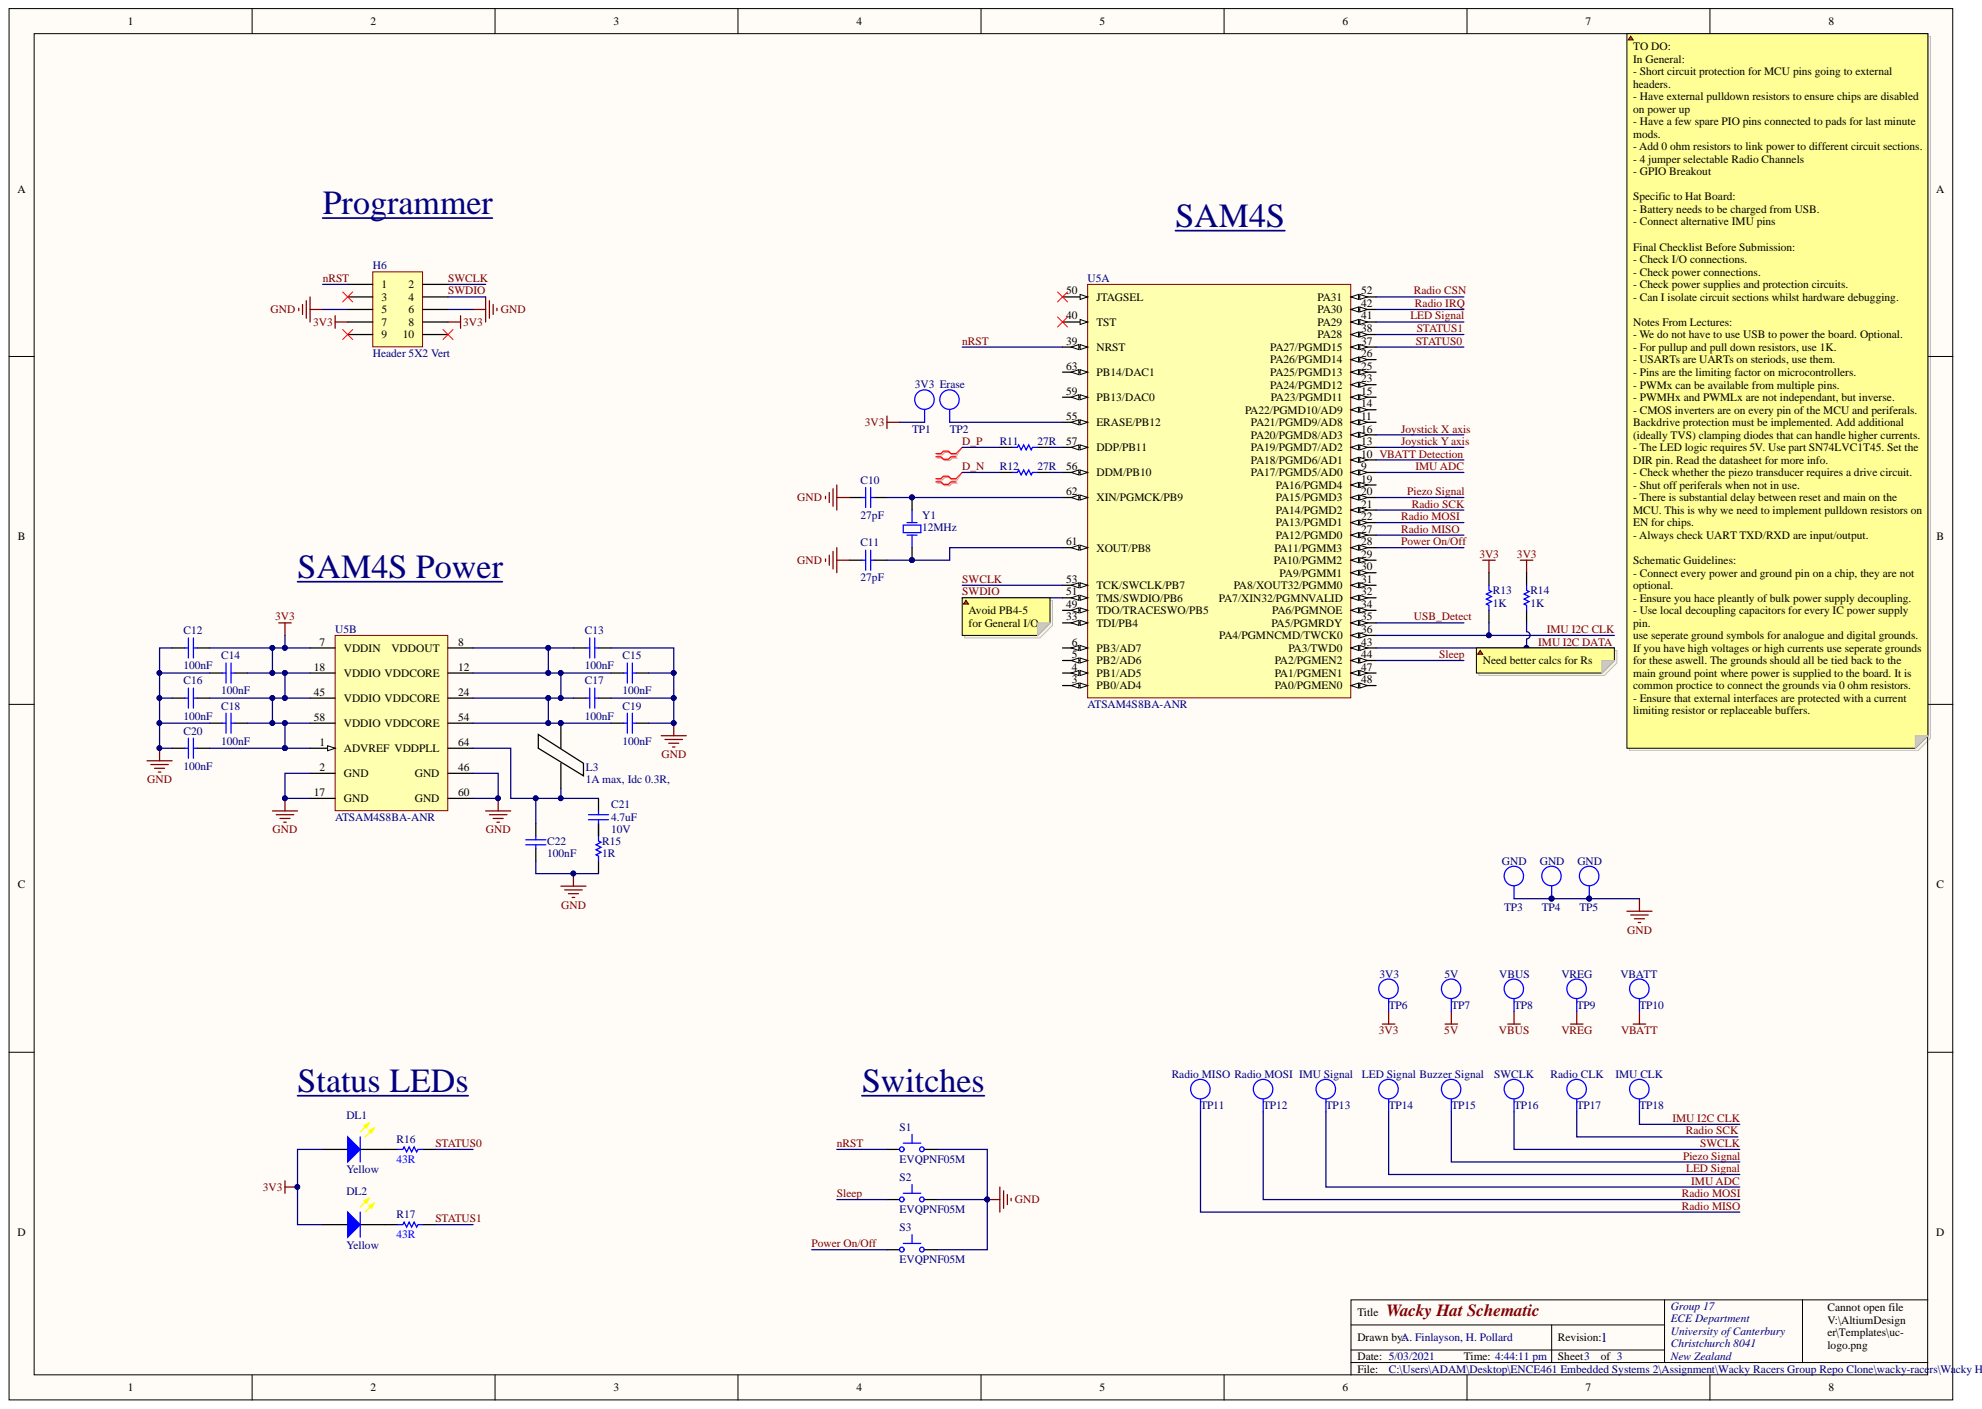
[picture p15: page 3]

In General:
- Short circuit protection for MCU pins going to external
headers.
- Have external pulldown resistors to ensure chips are disabled
on power up
- Have a few spare PIO pins connected to pads for last minute
mods.
- Add 0 ohm resistors to link power to different circuit sections.
- 4 jumper selectable Radio Channels
- GPIO Breakout

Specific to Hat Board:
- Battery needs to be charged from USB.
- Connect alternative IMU pins

Final Checklist Before Submission:
- Check I/O connections.
- Check power connections.
- Check power supplies and protection circuits.
- Can I isolate circuit sections whilst hardware debugging.

Notes From Lectures:
- We do not have to use USB to power the board. Optional.
- For pullup and pull down resistors, use 1K.
- USARTs are UARTs on steriods, use them.
- Pins are the limiting factor on microcontrollers.
- PWMx can be available from multiple pins.
- PWMHx and PWMLx are not independant, but inverse.
- CMOS inverters are on every pin of the MCU and periferals.
Backdrive protection must be implemented. Add additional
(ideally TVS) clamping diodes that can handle higher currents.
- The LED logic requires 5V. Use part SN74LVC1T45. Set the
DIR pin. Read the datasheet for more info.
- Check whether the piezo transducer requires a drive circuit.
- Shut off periferals when not in use.
- There is substantial delay between reset and main on the
MCU. This is why we need to implement pulldown resistors on
EN for chips.
- Always check UART TXD/RXD are input/output.

Schematic Guidelines:
- Connect every power and ground pin on a chip, they are not
optional.
- Ensure you hace pleantly of bulk power supply decoupling.
- Use local decoupling capacitors for every IC power supply
pin.
use seperate ground symbols for analogue and digital grounds.
If you have high voltages or high currents use seperate grounds
for these aswell. The grounds should all be tied back to the
main ground point where power is supplied to the board. It is
common proctice to connect the grounds via 0 ohm resistors.
- Ensure that external interfaces are protected with a current
limiting resistor or replaceable buffers.

Need better calcs for Rs

C:\Users\ADAM\Desktop\ENCE461 Embedded Systems 2\Assignment\Wacky Racers Group Repo Clone\wacky-racers\Wacky Hat\WackyHatProject\SAM4S_Piezo_LED.SchDoc

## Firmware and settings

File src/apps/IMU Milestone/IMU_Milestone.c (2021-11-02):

/*  File: IMU_Milestone.c
    Author: Adam Finlayson, Harrison Pollard
    Date: 11/05/2021
    Desc: Milestone Week 9. Working IMU and blinking LEDs
*/

#include "pit.h"
#include <stdio.h>
#include <pio.h>
#include <fcntl.h>
#include "target.h"
#include "pacer.h"
#include "usb_serial.h"
#include "mpu9250.h"
#include "math.h"
#include "nrf24.h"
#include "adc.h"
#include "pwm.h"

#define ADC_CLOCK_FREQ 24000000
#define PWM_FREQ_HZ 1000

/* Defines how fast the while loop is polled (Hz) */
enum
{
    POLL_RATE = 10
};

/* Defines how fast the LEDs are polled (Hz) */
enum
{
    LED_FLASH_RATE = 2
};

static int16_t motor_speed[2];
static int8_t sent = 0;

/* Defines the USB CDC configuration structure.
     Set = 0 for non-blocking I/O */
static usb_serial_cfg_t usb_serial_cfg =
    {
        .read_timeout_us = 1,
        .write_timeout_us = 1,
}; // Blocking I/O fills up buffers of info so code can still run while transmitting (eg UART)

static const pwm_cfg_t pwm1_cfg =
{
    .pio = PWM1_PIO,
    .period = PWM_PERIOD_DIVISOR (PWM_FREQ_HZ),
    .duty = PWM_DUTY_DIVISOR (PWM_FREQ_HZ, 50),
    .align = PWM_ALIGN_LEFT,
    .polarity = PWM_POLARITY_LOW,
    .stop_state = PIO_OUTPUT_LOW
};

/* Defines the TWI configuration structure. */
static twi_cfg_t mpu_twi_cfg =
    {
        .channel = TWI_CHANNEL_0,             // Sets the controller channel to 0
        .period = TWI_PERIOD_DIVISOR(100000), // 100 kHz Clock
        .slave_addr = 0                       // Not using as slave ?? Set to master (0)
};

static spi_cfg_t nrf_spi = {
    .channel = 0,
    .clock_speed_kHz = 1000,
    .cs = RADIO_CS_PIO,
    .mode = SPI_MODE_0,
    .cs_mode = SPI_CS_MODE_FRAME,
    .bits = 8,
};

static const adc_cfg_t adc_cfg1 =
{
    .bits = 12,
    .channel = ADC_CHANNEL_0,
    .trigger = ADC_TRIGGER_SW,
    .clock_speed_kHz = ADC_CLOCK_FREQ / 1000
};

static const adc_cfg_t adc_cfg2 =
{
    .bits = 12,
    .channels= BIT (ADC_CHANNEL_4) | BIT (ADC_CHANNEL_5),
    .trigger = ADC_TRIGGER_SW,
    .clock_speed_kHz = ADC_CLOCK_FREQ / 1000
};

/* Initialisation function for PIO components used in main */
uint8_t init_pio(void)
{
    // Initialise LED pins as pull up or down
    pio_config_set(LED1_PIO, PIO_OUTPUT_HIGH);
    pio_config_set(LED2_PIO, PIO_OUTPUT_LOW);

    // Initialise Radio Select Channel Pins (INPUT, LOW)
    pio_config_set(RADIO_S1, PIO_PULLUP);
    pio_config_set(RADIO_S2, PIO_PULLUP);
    pio_config_set(RADIO_S3, PIO_PULLUP);
    pio_config_set(RADIO_S4, PIO_PULLUP);

    // Initialise IMU vs Joystick controll
    pio_config_set(IMU_PIO, PIO_PULLDOWN);

    // printf("%d, ", pio_input_get(RADIO_S1));
    // printf("%d, ", pio_input_get(RADIO_S2));
    // printf("%d, ", pio_input_get(RADIO_S3));
    // printf("%d\n", pio_input_get(RADIO_S4));
    printf("%d\n", pio_input_get(IMU_PIO));

#ifdef RADIO_PWR_EN
    pio_config_set(RADIO_PWR_EN, PIO_OUTPUT_HIGH);
#endif

    return 1;
}

/* Initialisation function for USB used in main */
uint8_t init_usb(void)
{
    // Create non-blocking tty device for USB CDC connection.
    usb_serial_init(&usb_serial_cfg, "/dev/usb_tty"); // connects this file (stdin & stdout) to a read/write file

    freopen("/dev/usb_tty", "a", stdout); // freopen() makes printf work (connected to ubs_tty file)
    freopen("/dev/usb_tty", "r", stdin);

    return 1;
}

static void panic(void)
{
    while (1)
    {
        pio_output_set(LED1_PIO, 0);
    }
}

/* A function that prints the board tilt angle to a USB serial COM port */
void get_speed_from_imu(mpu_t *mpu)
{
    if (!mpu9250_is_imu_ready(mpu)) // Check if the IMU is ready
    {
        printf("Waiting for IMU to be ready...\n");
    }
    else
    {
        int16_t accel[3];       // Initialise an array of acceleration variables (x, y, z) to be read from the IMU
        int8_t theta[2];        // Initialise an array of angles

        if (mpu9250_read_accel(mpu, accel)) // Check if IMU data can be read
        {
            theta[0] = atan(((double_t)accel[0]) / ((double_t)accel[2])) * 180 / M_PI; // theta_xz (degrees)
            theta[1] = atan(((double_t)accel[1]) / ((double_t)accel[2])) * 180 / M_PI; // theta_yz (degrees)
            if (theta[0] > 25)
            {
                theta[0] = 25; // Ensure the maximum angle is 25 degrees
            }
            else if (theta[0] < -25)
            {
                theta[0] = -25;
            }
            if (theta[1] > 25)
            {
                theta[1] = 25; // Ensure the maximum angle is 25 degrees
            }
            else if (theta[1] < -25)
            {
                theta[1] = -25;
            }

            motor_speed[0] = (theta[0] * -20) + 250;
            motor_speed[1] = (theta[0] * -20) + 250;

            if (theta[1] >= 0)
            {
                motor_speed[1] = motor_speed[1] - (theta[1] * 10);
            }
            else
            {
                motor_speed[0] = motor_speed[0] + (theta[1] * 10);
            }

            if (accel[2] <= 0) {
                motor_speed[0] = 0;
                motor_speed[1] = 0;
            }
            
        }
        else
        {
            printf("ERROR: failed to read acceleration\n");
        }
    }
}

void get_speed_from_joystick(adc_t adc)
{
    uint16_t joystick_adc[2];
    int16_t mapped[2];

    adc_read (adc, joystick_adc, sizeof (joystick_adc));

    if (joystick_adc[0] < 1950 && joystick_adc[0] > 1850) {
        mapped[0] = 0; 
    } else {  
        mapped[0] = ((joystick_adc[0] - 1900) / 2) ;
    }
    if (joystick_adc[1] < 2130 && joystick_adc[1] > 2020) {
        mapped[1] = 0;
    } else {
        mapped[1] = ((joystick_adc[1] - 250 - 1875) / 2);
    }

    if (mapped[1] >= 0) {
        // Moving forward
        if (mapped[0] > 0) {
            // turning left
            motor_speed[0] = mapped[1] - mapped[0];
            motor_speed[1] = mapped[1];
        } else if (mapped[0] < 0) {
            // turn right
            motor_speed[0] = mapped[1];
            motor_speed[1] = mapped[1] + mapped[0];
        } else if (mapped[0] == 0) {
            motor_speed[0] = mapped[1];
            motor_speed[1] = mapped[1];
        }
    } else if (mapped[1] < 0) {
        // moving backwards
        motor_speed[0] = mapped[1];
        motor_speed[1] = mapped[1];
    }
}

uint8_t blink_led(uint8_t led_count)
{
    led_count++;                                     // Increase the LED counter
    if (led_count >= POLL_RATE / LED_FLASH_RATE * 2) // Check when LEDs should be turned on
    {
        led_count = 0; // Reset Counter

        pio_output_toggle(LED1_PIO); // Toggle LED 1
        pio_output_toggle(LED2_PIO); // Toggle LED 2
    }

    return led_count;
}

void data_tx(nrf24_t *nrf)
{
    char buffer[32];

    pio_output_toggle(LED2_PIO);
    pio_output_set(LED1_PIO, 1);

    sprintf(buffer, "%d,%d\r\n", motor_speed[1], motor_speed[0]);
    
    if (!nrf24_write(nrf, buffer, sizeof(buffer)))
    {
        pio_output_set(LED1_PIO, 0);
        // if (!sent)
        // {
        //     sent = 1;
        //     printf("ERROR: Data not sent.\n");
        // }
    }
    else
    {
        pio_output_set(LED1_PIO, 1);
        // if (sent)
        // {
        //     sent = 0;
        //     printf(buffer);
        // }
    }

}

int channel_select(void)
{
    int channel = 64;

    if (pio_input_get(RADIO_S1)) {
        channel = 120;
    } else if (pio_input_get(RADIO_S2)) {
        channel = 73;
    } else if (pio_input_get(RADIO_S3)) {
        channel = 91;
    } else if (pio_input_get(RADIO_S4)) {
        channel = 26;
    }

    printf ("Radio Channel: %d\n", channel);

    return channel;
}

uint16_t get_battery_voltage(adc_t adc)
{
    uint16_t bat_adc[1];
    adc_read (adc, bat_adc, sizeof (bat_adc));
    return bat_adc[0];
}

int main(void)
{
    mcu_jtag_disable();
    if (init_usb()) {
        printf("Serial Initialised\n");
    } // Initialise the USB
    pacer_init(POLL_RATE); // Initialise pacer poll rate
    if (init_pio()) {
        printf("PIO Initialised\n");
    } // Initialise the PIO

    // Initialise Variables
    int channel = channel_select();
    uint8_t flush_inits = 0;
    uint16_t battery_voltage = 0;

    pwm_t pwm1 = pwm_init (&pwm1_cfg);
    adc_t adc1 = adc_init (&adc_cfg1);
    adc_t adc2 = adc_init (&adc_cfg2);
    twi_t twi_mpu = twi_init(&mpu_twi_cfg);            // Initialise the TWI (I2C) bus for the MPU
    mpu_t *mpu = mpu9250_create(twi_mpu, MPU_ADDRESS); // Initialise the MPU9250 IMU
    spi_t spi = spi_init(&nrf_spi);
    nrf24_t *nrf;
    nrf = nrf24_create(spi, RADIO_CE_PIO, RADIO_IRQ_PIO);
    nrf24_begin(nrf, channel, 0x0548896548, 32);
    pwm_channels_start (pwm_channel_mask (pwm1) );

    printf(".............\n\n");

    while (1)
    {
        pacer_wait(); // Wait for 100ms

        if (pio_input_get(IMU_PIO)) {
            get_speed_from_imu(mpu); // Poll IMU
        } else {
            get_speed_from_joystick(adc2);
        }
 
        data_tx(nrf);

        // led_count = blink_led(led_count);
        battery_voltage = get_battery_voltage(adc1);
        if (battery_voltage < 2220) {

        }
        

        printf("\n");
        fflush(stdout); // Flushes the buffer so print functions are printed in time.
    }
}

/*  Notes:
        -   The IMU is initialised to a signed 16 bit interger, so the range of acceleration values
            are from 32,768 to 32,767.
        -   A value of 16,384 corresponds to 1G or 9.81m/s
        -   The movement of the racer will correspond with the tilt of the board (angle)
        -   The board angle can then be found by pythagorus (thetha = arctan( (x or y) /z ) )
*/

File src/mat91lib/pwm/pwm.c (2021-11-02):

/** @file   pwm.c
    @author M. P. Hayes
    @date   12 February 2008
    @brief  Pulse Width Modulation routines for AT91SAM7/SAM4S processors.
    This only drives the PWMHx signals; there is no support for the PWMLx
    signals.
*/

#include "mcu.h"
#include "pwm.h"
#include "bits.h"
#include "pinmap.h"


struct pwm_dev_struct
{
    /* Channel base.  */
    PwmCh_num *base;
    const pinmap_t *pin;
    pio_config_t stop_state;
    uint8_t prescale;
    pwm_period_t duty;
    pwm_period_t period;
};


#define PWM_DEVICES_NUM 4

static pwm_dev_t pwm_devices[PWM_DEVICES_NUM];


/* Define known PWMH pins, grouped by channel.  */
static const pinmap_t pwm_pins[] = 
{
    {0, PA0_PIO, PIO_PERIPH_A, PWM_POLARITY_HIGH},
    {0, PA11_PIO, PIO_PERIPH_B, PWM_POLARITY_HIGH},
    {0, PA23_PIO, PIO_PERIPH_B, PWM_POLARITY_HIGH},

    {1, PA1_PIO, PIO_PERIPH_A, PWM_POLARITY_HIGH},
    {1, PA12_PIO, PIO_PERIPH_B, PWM_POLARITY_HIGH},
    {1, PA24_PIO, PIO_PERIPH_B, PWM_POLARITY_HIGH},

    {2, PA2_PIO, PIO_PERIPH_A, PWM_POLARITY_HIGH},
    {2, PA13_PIO, PIO_PERIPH_B, PWM_POLARITY_HIGH},
    {2, PA25_PIO, PIO_PERIPH_B, PWM_POLARITY_HIGH},

    {3, PA7_PIO, PIO_PERIPH_B, PWM_POLARITY_HIGH},
    {3, PA14_PIO, PIO_PERIPH_B, PWM_POLARITY_HIGH},

#ifdef _SAM4S_
    /* SAM4S  64 pin.  TODO, support PCx on 100 pin devices.  */
    {0, PB0_PIO, PIO_PERIPH_A, PWM_POLARITY_HIGH},
    {1, PB1_PIO, PIO_PERIPH_A, PWM_POLARITY_HIGH},
    {2, PB4_PIO, PIO_PERIPH_B, PWM_POLARITY_HIGH},
    {3, PA17_PIO, PIO_PERIPH_C, PWM_POLARITY_HIGH},
    {3, PB14_PIO, PIO_PERIPH_B, PWM_POLARITY_HIGH},

    {0, PA19_PIO, PIO_PERIPH_B, PWM_POLARITY_LOW},
    {0, PB5_PIO, PIO_PERIPH_B, PWM_POLARITY_LOW},
    {1, PA20_PIO, PIO_PERIPH_B, PWM_POLARITY_LOW},
    {1, PB12_PIO, PIO_PERIPH_A, PWM_POLARITY_LOW},
    {2, PA30_PIO, PIO_PERIPH_A, PWM_POLARITY_LOW},
    {2, PA16_PIO, PIO_PERIPH_C, PWM_POLARITY_LOW},
    {2, PB13_PIO, PIO_PERIPH_A, PWM_POLARITY_LOW},
    {3, PA15_PIO, PIO_PERIPH_C, PWM_POLARITY_LOW},
#endif
};


#define PWM_PINS_NUM ARRAY_SIZE (pwm_pins)



/** Shutdown clock to PWM peripheral.  */
void
pwm_shutdown (void)
{
    /* Disable PWM peripheral clock.  */
    mcu_pmc_disable (ID_PWM);
}


static void
pwm_prescale_set (pwm_t pwm, uint8_t prescale)
{
    /* Configure prescaler.  */
    BITS_INSERT (pwm->base->PWM_CMR, prescale, 0, 3);
    pwm->prescale = prescale;
}


/** Set waveform period (in CPU clocks).  This will change the 
    prescaler as required.  This will block if the PWM is running until 
    the end of a cycle.  */
pwm_period_t
pwm_period_set (pwm_t pwm, pwm_period_t period)
{
    pwm_channel_mask_t mask;
    uint8_t prescale;

    if (pwm->period != 0)
    {
        pwm_period_t duty;

        /* If change period, need to adjust duty pro-rata.  */
        duty = (period * pwm->duty) / pwm->period;
        pwm_duty_set (pwm, duty);
    }
    pwm->period = period;

    /* If the period is greater than 16-bits then need to select the
       appropriate prescaler.  This can be from 1 to 1024 in powers 
       of 2.  */
    for (prescale = 0; prescale < 11 && period >= 65535u; prescale++)
    {
        period >>= 1;
    }

    /* TODO: it is possible to configure CLKA and CLKB to have an even
       lower frequency.  However, these clocks are shared for all
       channels.  */
    if (period > 65535u)
        return 0;

    pwm_prescale_set (pwm, prescale);

    mask = pwm_channel_mask (pwm);

    /* Configure period.  */
    if (PWM->PWM_SR & mask)
    {
        uint8_t status;

        /* The PWM is running.  We need to jump through a hoop to
           update the period register.  This is because the update 
           register is shared for updating both the period and for 
           the duty.  */

        /* Read update status.  */
        status = BITS_EXTRACT (PWM->PWM_ISR1, 0, 3); 

        /* Set mode to update period.  */
        BITS_INSERT (pwm->base->PWM_CMR, 1, 10, 10);
        
        /* Wait for a new period.  */
        while (!(status & mask))
        {
            status = BITS_EXTRACT (PWM->PWM_ISR1, 0, 3);
        }

        pwm->base->PWM_CPRDUPD = period;
    }
    else
    {
        pwm->base->PWM_CPRD = period;
    }

    return period << pwm->prescale;
}


pwm_period_t
pwm_period_get (pwm_t pwm)
{
    return pwm->base->PWM_CPRD << pwm->prescale;
}


pwm_frequency_t
pwm_frequency_set (pwm_t pwm, pwm_frequency_t frequency)
{
    pwm_period_t period;

    period = PWM_PERIOD_DIVISOR (frequency);
    period = pwm_period_set (pwm, period);

    return F_CPU / period;
}


/** Set waveform duty (in CPU clocks).  This will block if the 
    PWM is running until the end of a cycle.  */
pwm_period_t
pwm_duty_set (pwm_t pwm, pwm_period_t duty)
{
    pwm_channel_mask_t mask;

    pwm->duty = duty;
    duty = duty >> pwm->prescale;

    mask = pwm_channel_mask (pwm);

    /* Configure duty.  */
    if (PWM->PWM_SR & mask)
    {
        uint8_t status;

        /* The PWM is running.  We need to jump through a hoop to
           update the duty register.  This is because the update 
           register is shared for updating both the period and for 
           the duty.  */

        /* Read update status.  */
        status = BITS_EXTRACT (PWM->PWM_ISR1, 0, 3); 

        /* Set mode to update duty.  */
        BITS_INSERT (pwm->base->PWM_CMR, 0, 10, 10);
        
        /* Wait for a new duty.  */
        while (!(status & mask))
        {
            status = BITS_EXTRACT (PWM->PWM_ISR1, 0, 3);
        }

        pwm->base->PWM_CDTYUPD = duty;
    }
    else
    {
        pwm->base->PWM_CDTY = duty;
    }

    return duty << pwm->prescale;
}


pwm_period_t
pwm_duty_get (pwm_t pwm)
{
    return pwm->base->PWM_CDTY << pwm->prescale;
}


/** Set waveform duty (as a fraction of the period in parts per
    thousand).  This will block if the PWM is running until the end of
    a cycle.  */
unsigned int
pwm_duty_ppt_set (pwm_t pwm, unsigned int duty_ppt)
{
    pwm_period_t duty;
    pwm_period_t period;
 
    period = pwm_period_get (pwm) >> pwm->prescale;
    duty = period * duty_ppt / 1000;

    duty = pwm_duty_set (pwm, duty << pwm->prescale) >> pwm->prescale;
    
    return duty * 1000 / period;
}
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
